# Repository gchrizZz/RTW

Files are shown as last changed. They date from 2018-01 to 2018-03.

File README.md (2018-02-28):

# RTW

Über dieses gitrepository können wir parallel am "Road to Wattens" - Projekt arbeiten.

Ordnerstruktur:
- 01_Projektmanagement:  Bereich für Bericht und Organisation
- 02_Quellcode:          Bereich für die Programmierung des Quadrocopters
- 03_Konstruktion:       Bereich für die CAD-Teile des Quadrocopters 
- 04_Elektrik:     Bereich für Platinenlayouts und Circuits
- 99_Archiv:             Bereich für Ablage und nicht mehr relevante Artefakte

CAD Modell von Mohne:
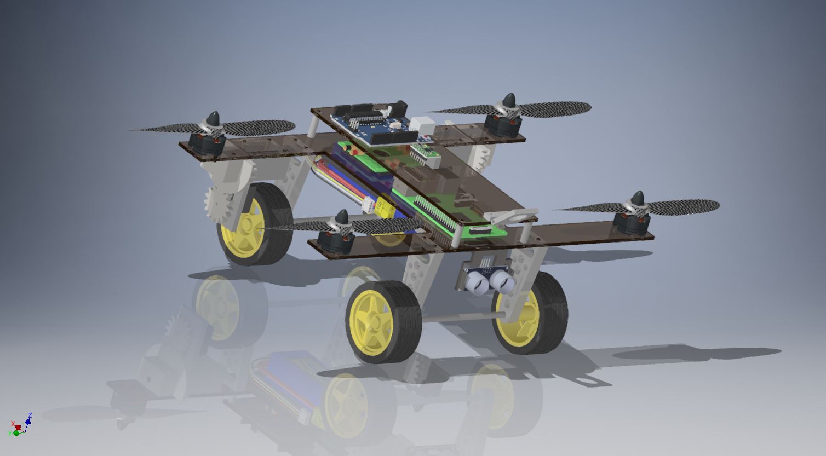
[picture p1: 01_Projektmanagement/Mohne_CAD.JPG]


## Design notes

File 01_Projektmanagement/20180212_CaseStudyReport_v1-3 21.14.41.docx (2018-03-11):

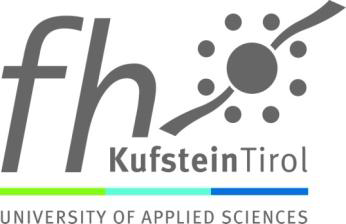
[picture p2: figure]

Mohne – Mobile Drohne

Abschlussbericht

Entwicklung eines autonomen Fahrzeuges für extraterrestrische Erkundungsmissionen

Eingereicht bei:

Fachhochschule Kufstein Tirol Bildungs GmbH

Studiengang Smart Products & Solutions

Verfasser:

Markus Wiesmüller

1710809534

Abgabedatum:

11.03.2018

# List of Figures

# List of Tables

# List of Abbreviation

IoT | Internet of Things
GM | Geschäftsmodell
GMI | Geschäftsmodell-Innovation
DBT | Digital Business Transformation
IT | Informationstechnik
EY | Ernst & Young
ROI | Return on Investment
KPI | Key Performance Indicator
MIT | Massachusetts Institute of Technologie
IKT | Informations- und Kommunikationstechnik
HR | Human Resources
BDI | Bundesverband der Deutschen Industrie e.V.
CEO | Chief Executive Officer
F&E | Forschung und Entwicklung

# Kurzfassung

In diesem Jahrhundert werden Menschen zum ersten Mal ihre Füße auf den Planeten Mars setzen – zumindest sehen dies durchaus realistische Pläne diverser Raumfahrtorganisationen. Bis es jedoch soweit ist, müssen weitere Projekte wie Phoenix oder InSight durchgeführt werden, um weitere Informationen über die Entstehung des Mars zu sammeln. Die Aufgabe, welche daher für das Projekt gestellt wurde, war die Entwicklung eines autonom agierenden Fahrzeugs, welches den widrigen Bedingungen auf dem Mars standhalten würde. Nach reichlicher Überlegung kamen wir zu dem Entschluss, dass eine Hybriddrohne, welche sowohl fahren als auch fliegen kann am besten für die Erkundungsmission geeignet sei, da dadurch die Möglichkeit gegeben ist, große Höhenunterschiede wie Berge oder Schluchten mühelos zu bewältigen und einen erheblichen Vorteil gegenüber konventionellen Mars-Rovern darstellt. Um diese Annahme zu bestätigen, hat das Team unterschiedliche Designvariationen in Betracht gezogen, bevor wir uns entschlossen haben einen Hybrid-Quadrocopter zu bauen. Die Nutzlast unserer Drohne umfasst eine Kamera und einen Ultraschallsensor, wodurch der Drohne ermöglicht wird sich autonom fortzubewegen. Hinsichtlich Projektmanagementmethodik entschieden wir uns für einen traditionellen Ansatz für die Gesamtplanung und für eine agile Methodik für die Einzelaufgaben.

Um die benötigten Komponenten für die Drohne zu produzieren wurden vom Fablab in Wattens die entsprechenden Maschinen und Geräte sowie hilfreiche Unterstützung zur Verfügung gestellt.

Um festzustellen, ob der Mars-Rover für einen Einsatz auf dem Mars geeignet ist, mussten fünf verschiedene Tracks absolviert werden. Es stellte sich jedoch schnell heraus, dass ein stabiler Flug und somit ein überwinden von Hindernissen aufgrund der fehlenden PID-Regelung nicht möglich war.

Letztendlich war dieses Konzept in der vorgegebenen Zeit für uns nicht realisierbar, weshalb man sich besser für ein anderes Design entschieden hätte. Man sollte sich daher nicht für ein Konzept entscheiden, von welchem man überzeugt ist, welches mit den gegebenen Ressourcen jedoch nicht umsetzbar ist. Dennoch zeigte unsere Drohne, dass sie bei weiterer Entwicklung das Potential für einen Einsatz auf dem Mars hat.

# Abstract

In this century, humans will set their feet on the planet Mars for the first time - at least this is what realistic plans of various space organisations see. Until then, however, further projects such as Phoenix or In-Sight will have to be carried out in order to gather further information on the origin of Mars. The task, therefore, was to develop an autonomous vehicle that would withstand the adverse conditions on Mars. After a lot of discussions, we came to the conclusion that a hybrid drone, which can drive as well as fly, is best suited for exploration missions, as it offers the possibility to effortlessly cope with big differences in altitude like mountains or canyons and represents a considerable advantage compared to conventional Mars rovers. To confirm this assumption, the team considered different design variations before we decided to build a hybrid quadrocopter. The payload of our drone includes a camera and an ultrasonic sensor, which enables the drone to move autonomously. With regard to project management methodology, we opted for a traditional approach to overall planning and an agile methodology for the individual tasks.

In order to produce the required components for the drone, the Fablab in Wattens provided the appropriate machines and equipment as well as helpful support.

In order to determine whether the Mars rover is suitable for a mission on Mars, five different tracks had to be completed. However, it soon became clear that a stable flight and thus the overcoming of obstacles was not possible due to the lack of PID regulation.

Ultimately, this concept was not feasible for us in the given time, which is why it would have been better to opt for a different design. Therefore, you should not decide on a concept that you are convinced of, but which cannot be implemented with the given resources. Nevertheless, our drone showed that it has the potential to be used on Mars during further development.

# 1. System Beschreibung

## 1.1 Mechanisches Konzept

Die Mohne ist ein sogenannter „Hybrid-Quadrocopter“, der sowohl zum Fahren als auch zum Fliegen konzipiert ist. Durch diese Hybrid-Nutzung ergeben sich große Vorteile. Auf dem Boden spart der Roboter Energie (im Verhältnis zur Fortbewegung in der Luft), während er in der Luft auch meterhohe Hindernisse überwinden kann. Nachfolgend wird das mechanische Konzept beider Varianten näher erläutert sowie in Abbildung 5 veranschaulicht.

### 1.1.1 Flugmodus

Die Mohne gehört zur Gruppe der Quadrocopter, bestehend aus vier Motoren die in H-Konfiguration angeordnet sind. Bei der H-Konfiguration sind die vier Motoren in 45° zur Flugrichtung versetzt, wobei der Abstand vom Kreuzmittelpunkt zu den einzelnen Motoren immer gleich groß ist.

Vier Propeller sind fest an den Motoren montiert und erzeugen den Auftrieb der Drohne, welcher sich über die Drehzahl der einzelnen Motoren verändern lässt. Übersteigt die durch die sich drehenden Propeller erzeugte Auftriebskraft die Anziehungskraft der Erde bzw. des Mars, so beginnt die Drohne zu schweben. Eine Erhöhung bzw. Verringerung der Drehzahl hat ein Steigen bzw. ein Sinken der Drohne zufolge.

Dadurch ergibt sich ein relativ einfacher mechanischer Aufbau, in dem es außer den Rotoren der Motoren keine weiteren beweglichen Teile für den Flugmodus gibt.

Überkreuz liegende Rotoren drehen dabei in die gleiche Richtung (Abbildung 1) und heben somit das um die Mitte der Drohne übertragene Drehmomente auf.

Bei exakt gleicher Drehgeschwindigkeit aller Propeller und keinen äußeren Störeinflüssen, steht die Drohne also exakt lotrecht über dem Boden. Dies eliminiert die Notwendigkeit einer Gierstabilisierung.

Um ein nach vorne fliegen zu ermöglichen, drehen sich die vorderen Rotoren langsamer als die hinteren, was ein nach vorne abkippen der Drohne zur Folge hat (Abbildung 2). Entsprechend wird ein nach hinten fliegen ermöglicht, indem die hinteren Rotoren langsamer als die vorderen drehen (Abbildung 3).

Abbildung 1: Quadrocopter: Motordrehrichtung

Abbildung 2: Quadrocopter: Vorwärtsbewegung

Abbildung 3: Quadrocopter: Rückwärtsbewegung

### 1.1.2 Fahrmodus

Um mit der Mohne auch fahren zu können, wurde eine Radaufhängung mit Achsen an die Drohne montiert. Allerdings werden dabei die Räder nicht von einem Motor betrieben, stattdessen wird die Schubleistung von den Propellern der Mohne erzeugt. Die hinteren Tragflächen des Quadrocopters lassen sich im Fahrmodus über Zahnräder um nahezu 90° nach vorne und hinten verstellen (Abbildung 4). In diesem Modus drehen sich nur die hinteren Propeller, wodurch ein Vorschub ähnlich wie bei einem Flugzeug bzw. Schiff erzeugt wird. Ein Abbremsen erfolgt indem die Propeller auf Umkehrschub gestellt werden. Sie erzeugen so einen nach vorne gerichteten Schub. Die Verstellung erfolgt dabei elektrisch.

+90°

-90°

Abbildung 4: Tragfläche mit Propeller: Verstellbar um +90° und -90°

### 1.1.3 Funktionsprinzip der Propeller

Wichtig für das Verständnis des Funktionsprinzips der Drohne ist, dass man sich grob phänomenologisch die Wirkungsweise von Propellern veranschaulicht, weil sich schon aus recht simplen Überlegungen Hinweise darauf ergeben, wie die Propeller sinnvollerweise ausgelegt werden müssen. Die Wirkungsweise eines Propellers, dessen Aufgabe sowohl im Flug- als auch im Fahrmodus darin besteht eine Drehleistung von 2πQn optimal in eine Schubleistung T_(v_A) umzusetzen, kann aus zwei Anschauungen gewonnen werden, die dann in jeweils unterschiedlichen Berechnungsmodellen münden:

- Impulsbetrachtung: Um einen Schub T nach vorne bzw. nach oben zu erzeugen, muss der Propeller die Luft nach hinten bzw. nach unten beschleunigen. Die Änderung des Impulses entspricht dabei dem Propellerschub. Die Theorie, die auf diesem Modell aufbaut, ist die Strahltheorie.
- Tragflügelbetrachtung: Die Wirkungsweise eines Propellers entspricht der eines Tragflügels. Der Auftrieb entspricht dabei dem Schub, der Widerstand dem Moment. Das Tragflügelmodell erklärt die Propellerwirkung an den einzelnen Flügelschnitten und ist als Traglinentheorie (nur radiale Diskretisierung) oder Tragflächentheorie bekannt.

Aus diesen beiden Wirkungsweisen lassen sich schon einige grundlegende Dinge qualitativ ableiten, ohne dass genaue mathematische Begründungen nötig sind.

Abbildung 5: Quadrocopter: Mechanisches Konzept

Motor

+

Propeller

Motor

+

Propeller

Motor

+

Propeller

Motor

+

Propeller

Rad

Rad

Rad

Rad

Servo

Servo

## 1.2 Sensing Concept

Um die Mohne autonom fliegen bzw. fahren zu lassen und Hindernisse und Ziele zu erkennen, wurde eine Kamera und ein Ultraschallsensor verbaut. Nachfolgend werden beide Sensoren näher beschrieben und das System im Gesamtkontext betrachtet.

### 1.2.1 Picamera

Mit der Kamera sollen vorher definierte Formen und Farben erkannt werden. Die Rückgabewerte an den Raspberry Pi sollen in der Logik die vorgesehene Funktion auslösen. Beispiele hierfür sind markierte Hindernisse und das Ziel. Anbei ein Auszug an angelernten Formen und Farben (Abbildung 6), hier ist auch das vorgegebene rote Quadrat enthalten. Die exakte Größe spielte keine Rolle, da wir in der Logik Ecken und Kanten zählen haben lassen und Farben erkennen.

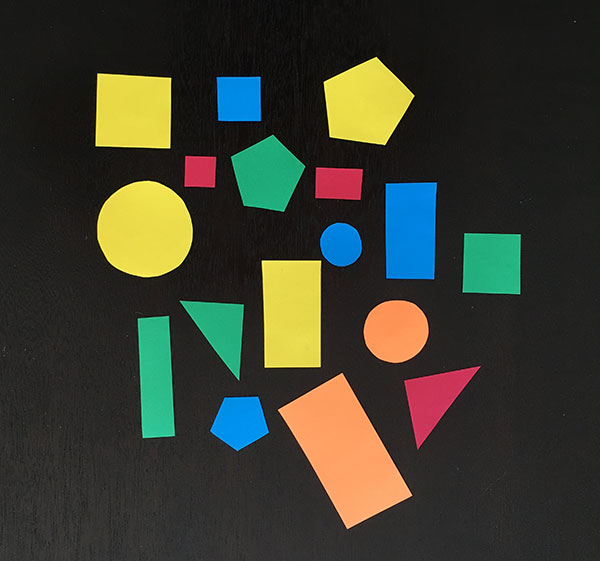
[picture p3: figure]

Abbildung 6: Angelernte Formen und Farben

### 1.2.2 Ultraschallabstandssensor

Mit dem Ultraschallabstandssensor (Abbildung 7) kann man mittels eines Ultraschalllautsprechers und eines Mikrofons den Abstand berührungslos zu einem Objekt messen. Das Prinzip (Abbildung 8) basiert darauf, dass die Schallgeschwindigkeit in der Luft bei gleichbleibender Temperatur nahezu konstant bleibt - bei 20°C beträgt sie 343,2m/s. Aus diesem Fakt kann man die Abstandsmessung in eine Zeitmessung überführen, welche dann von Mikro-Controllern einfach übernommen werden kann.

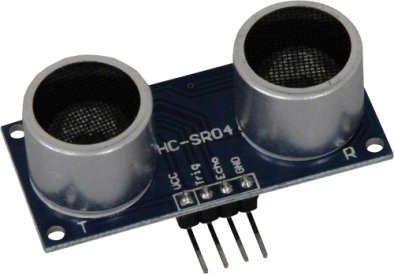
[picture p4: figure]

Abbildung 7: Ultraschallabstandssensor

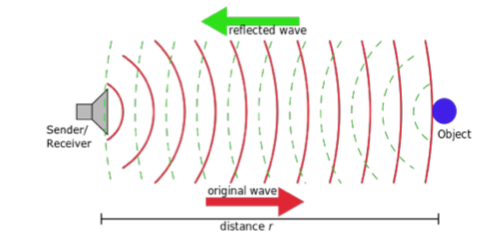
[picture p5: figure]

Abbildung 8: Funktionsprinzip Ultraschallabstandssensor

### 1.2.3 Gesamtsystem

Die unter Punkt 1.2.1 und 1.2.2 beschriebenen Sensoren unterstützen den Hybrid-Quadrocopter sich in seiner Umgebung zurechtzufinden und sich autonom fortzubewegen, Ziele zu erkennen und Hindernisse gekonnt zu überfliegen. Die Picamera dient dazu ein Ziel zu erkennen und dieses anzusteuern, mit Hilfe des Ultraschallsensors kann ein Hindernis erkannt werden, woraufhin in den Flugmodus gewechselt wird, um das Hindernis zu überfliegen und um nach einer bestimmten Zeit x zu landen und wieder in den Fahrmodus zu wechseln. Wie in Abbildung 9 veranschaulicht sind dabei beide Sensoren mit einem Micro-Controller verbunden.

Abbildung 9: Quadrocopter: Sensorkonzept

Controller

Kamera

Ultraschallsensor

# 2. Materialien und Methoden

Um das Projekt zu realisieren und die Mohne zu entwickeln, wurde Seitens des Auftraggebers verschiedene Materialien und Werkzeugmaschinen sowie ein Budget von 40€ zur Verfügung gestellt.

Es gab viele Faktoren, die dazu beitrugen, wie dieser Hybrid-Quadrocopter konstruiert werden sollte. Das Team musste zuerst berücksichtigen, dass die Drohne Testflüge absolvieren musste, von denen sie gegebenenfalls nicht in einem Stück zurückkehrt. Hinzu kam, dass das Gewicht der für die Herstellung der Drohne verwendeten Materialien sorgfältig geprüft werden musste, damit das Gewichtslimit und auch die Größe für den Wettbewerb nicht überschritten wurde. Schließlich musste das Design auf eine Art und Weise erstellt werden, welches leicht mit den zur Verfügung stehenden Materialien und Werkzeugmaschinen umgesetzt werden konnte. Zudem musste das Design die Elektronik vor Wasser schützen. Aufgrund des entscheidensten Faktors, die für die Produktion zur Verfügung stehenden Zeit, wurde entschieden, Lasercutten, 3D-Druck, Schneiden, Schleifen, Fräsen und verbinden mit Schrauben zu verwenden. Dieser Prozess wurde als am schnellsten und am leichtesten reproduzierbar bestimmt, falls erforderlich. Der erste Schritt in diesem Prozess war das Design der Drohne zu entwerfen. Dafür wurde die in Abschnitt 2.3.1 beschriebene CAD-Software Autodesk Inventor verwendet. Im nächsten Schritt wurde bestimmt, wie die einzelnen Komponenten hergestellt und welche Materialen dafür verwendet werden sollten. Komponenten wir Arduino, Raspberry Pi und Sensoren wurden zur Verfügung gestellt. Da jedoch kein Breadboard verwendet werden durfte, wurde mit Hilfe der in 2.3.2 beschriebenen Software ein Leiterplatten-Layout erstellt, welches mit Hilfe einer Fräsmaschine gefertigt wurde.

In diesem Kapitel werden die bereitgestellten Materialien aufgelistet, die verfügbaren Maschinen vorgestellt sowie eine Vorstellung der verwendeten Software.

## 2.1 Materialien

Aus der Tabelle 1 sind die Materialien und Maße der vom Kunden zur Verfügung gestellten Werkstoffe ersichtlich.

Tabelle 1: Zur Verfügung gestelltes Material

Material | Maße in mm (l x b x h)
Holz | 800 x 600 x 3,8
Plexiglas | 600 x 400 x 3

## 2.2 Manufacturing Technologies

Um das Projekt zu realisieren kamen unterschiedliche Werkzeugmaschinen zum einsatz, welche aus Tabelle 2 ersichtlich sind. Auf eine nähere Beschreibung der Handhabung der Maschinen wird in diesem Bericht bewusst verzichtet.

Tabelle 2: Werkzeug und Maschinen

Werkzeug / Maschine
Bohr-Fräsmaschine Optimum BF 16 Vario

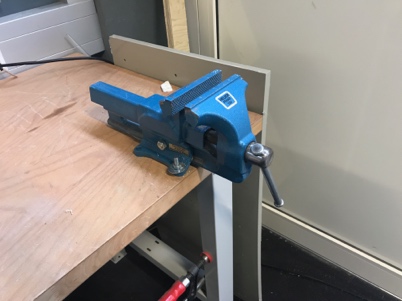
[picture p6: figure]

Schraubstock
Schleifmaschine Holzstar BTS 150

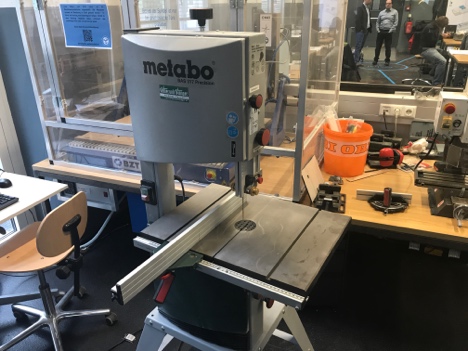
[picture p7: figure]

Bandsäge Metabo BAS 317 Precision
Digitaler Messschieber Scala 150mm

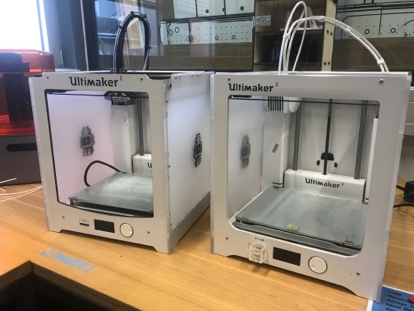
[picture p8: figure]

Ultimaker 2 3D-Drucker
Ultimaker 3 Dual Extruder 3D-Drucker
Fräsmaschine Roland SRM-20

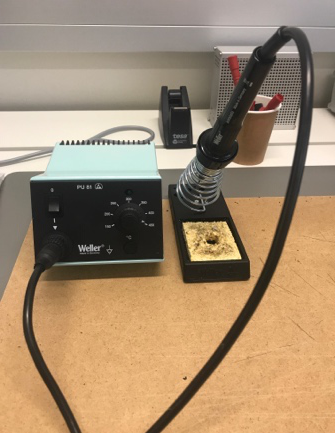
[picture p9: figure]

Lötstation Weller WS 81
Lasergravierer Trotec Speedy 360

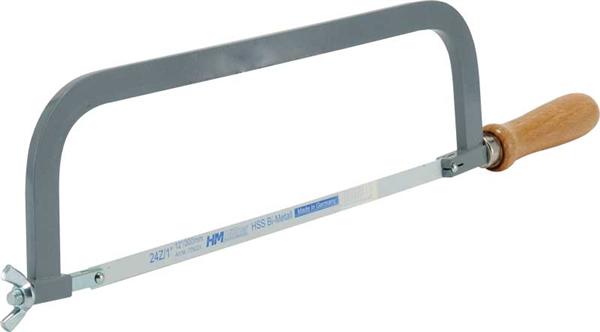
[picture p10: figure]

Metallsäge
Schraubenzieher

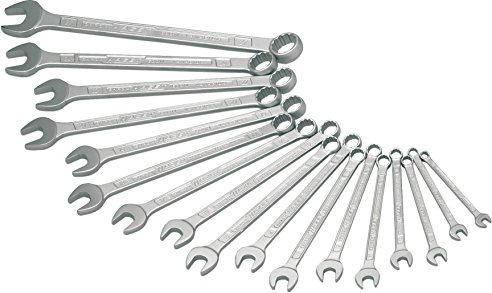
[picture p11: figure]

Schraubenschlüssel

## 2.3 Software Tools

Um das Projekt zu realisieren, wurden die nachfolgenden Softwareprogramme verwendet. Zum einen wurde Autodesk Inventor Professional verwendet, um ein 3D CAD-Modell der Mohne zu erstellen (Abbildung 10). Die einzelnen Komponenten sind in Tabelle 3 aufgelistet. Zum anderen wurde für die Konstruktion der Leiterplatte das Programm EAGLE der Firma Autodesk verwendet. Weitere Software Tools wurden für die Programmierung benötigt.

### 2.3.1 Autodesk Inventor Professional

Autodesk Inventor ist eine von Autodesk entwickelte 3D-CAD-Software für die Volumenmodellierung, mit der digitale 3D-Prototypen erstellt werden können. Es wird für 3D-Konstruktion, Design-Kommunikation, Werkzeugherstellung und Produktsimulation verwendet. Diese Software ermöglicht es Benutzern, genaue 3D-Modelle zu erstellen, um Produkte zu entwerfen, zu visualisieren und zu simulieren, bevor sie gebaut werden.


Die Software ermöglicht zudem 2D- und 3D-Daten in eine einzige Designumgebung zu integrieren und so eine virtuelle Darstellung des Endprodukts zu erstellen, mit der die Form, Passform und Funktion des Produkts vor dem Bau validieren werden kann. Autodesk Inventor enthält leistungsstarke parametrische, direkte Bearbeitungs- und Freiform-Modellierungswerkzeuge sowie Multi-CAD-Übersetzungsfunktionen und DWG Zeichnungen nach Industriestandard, wodurch Entwicklungskosten gesenkt, schnellere Time-to-Market realisiert und großartige Produkte entwickelt werden können.

Abbildung 10: CAD-Modell des Hybrid-Quadrocopters

Tabelle 3: Komponentenübersicht

Name | Anzahl
Chassis mit motorlöcher | 1
Platzhalter Zylinder Klein | 4
Metall Stab M5 | 1
Chassis-2 | 1
Kegelrad | 1
EMax Motor | 4
RaspberryPi2 STEP214 | 1
Metall Stab M5_MIR | 1
StirnradUNDServo_MIR | 1
Propeller | 4
arduino uno | 1
MPU 6050 IMU | 1
Abstandhalter_MPU | 1
LiPo Akku | 1
PDB | 4
Ultrasonic Sensor Halterung | 1
USS | 1
Wheel ALL | 2
Radaufhängung | 4
Wheel ALL1_MIR | 2
Achse | 2
Kamerahalterung | 1
ESC | 4
M3 Schrauben | 27
M3 Beilagscheiben | 27
M3 Muttern | 27
Raspberry Pi Camera | 1
Stirnzahnrad1 | 2
Stirnzahnrad2 | 2
servo_SM-S2309S | 2

### 2.3.2 Autodesk EAGLE

EAGLE ist eine skriptfähige EDA-Anwendung (Electronic Design Automation) mit Schaltplan-Erfassung, Leiterplatten-Layout, Auto-Router und CAM-Funktionen (Computer Aided Manufacturing). EAGLE steht dabei für Easy Applicable Grafischer Layout-Editor.

Das Programm bietet eine grafische Benutzeroberfläche und ein Menüsystem mit mehreren Fenstern für die Bearbeitung, das Projektmanagement und die Anpassung der Schnittstellen- und Designparameter. Das System kann über Maus, Tastaturkürzel oder durch Eingabe bestimmter Befehle in einer eingebetteten Befehlszeile gesteuert werden. Mehrere Wiederholungsbefehle können zu Skriptdateien kombiniert werden. Es ist auch möglich, Entwurfsdateien unter Verwendung einer EAGLE-spezifischen objektorientierten Programmiersprache zu untersuchen.

### 2.3.3 Arduino IDE

Arduino bringt eine eigene integrierte Entwicklungsumgebung (IDE) mit, die auf Wiring IDE basiert. Dabei handelt es sich um eine Java-Anwendung, die für die gängigen Plattformen Windows, Linux und MacOS kostenlos verfügbar ist. Sie basiert auf der IDE von Processing, einer auf die Einsatzbereiche Grafik, Simulation und Animation spezialisierten Entwicklungsumgebung. Die Arduino-IDE bringt einen Code-Editor mit und bindet gcc als Compiler ein. Zusätzlich werden die avr-gcc-Library und weitere Arduino-Librarys eingebunden, die die Programmierung in C und C++ stark vereinfachen. Arduino kann verwendet werden, um eigenständige interaktive Objekte zu steuern oder um Softwareanwendungen auf Computern zu interagieren (z.B. Adobe Flash, Processing, Max/MSP, Pure Data, diverse Skriptsprachen, etc.)

Für ein funktionstüchtiges Programm genügt es, zwei Funktionen zu definieren:

- setup() – wird beim Start des Programms (entweder nach dem Übertragen auf das Board oder nach Drücken des Reset-Tasters) einmalig aufgerufen, um z. B. Pins als Eingang oder Ausgang zu definieren.
- loop() – wird durchgehend immer wieder durchlaufen, solange das Arduino-Board eingeschaltet ist.

### 2.3.4 Raspbian

Raspbian ist ein kostenloses Betriebssystem, das auf Debian basiert und für die Raspberry Pi-Hardware optimiert ist. Ein Betriebssystem ist die Menge der grundlegenden Programme und Dienstprogramme, die den Raspberry Pi laufen lassen. Raspbian bietet jedoch mehr als ein reines Betriebssystem: Es enthält mehr als 35.000 Pakete, vorkompilierte Software in einem schönen Format für die einfache Installation auf dem Raspberry Pi. Dieses Betriebssystem basiert auf einem Debian-9-System (Debian Stretch) der ARM-hard-float-Architektur (armhf) mit Anpassungen an den Befehlssatz für den ARMv6-Prozessor. Als grafische Oberfläche wird LXDE vorkonfiguriert. Das etwa 3 GB große Image kann auf SD-Karten mit 4 GB oder mehr übertragen werden. Nach dem Bootvorgang kann die Größe der Raspbian-Partition auf die gesamte SD-Karte erweitert werden. Die Raspberry Pi Foundation erstellt auf Basis der Raspbian-Distribution ein eigenes Raspbian-Image mit passender Firmware für die Raspberry-Pi-Modelle, es wird daher empfohlen, die Distribution immer von der Raspberry Pi Foundation zu beziehen.

### 2.3.5 Python

Das Pi im Namen des Raspberry Pi leitet sich von der Programmiersprache Python ab: Die Schöpfer des Minicomputers wollten damit zum Ausdruck bringen, dass diese moderne Skriptsprache besonders zu empfehlen ist.

Python ist eine universelle, üblicherweise interpretierte höhere Programmiersprache. Sie hat den Anspruch, einen gut lesbaren, knappen Programmierstil zu fördern. So werden beispielsweise Blöcke nicht durch geschweifte Klammern, sondern durch Einrückungen strukturiert.

Python unterstützt mehrere Programmierparadigmen, z. B. die objektorientierte, die aspektorientierte und die funktionale Programmierung. Ferner bietet es eine dynamische Typisierung. Wie viele dynamische Sprachen wird Python oft als Skriptsprache genutzt.

Die Sprache hat ein offenes, gemeinschaftsbasiertes Entwicklungsmodell, das durch die gemeinnützige Python Software Foundation, die de facto die Definition der Sprache in der Referenzumsetzung CPython pflegt, gestützt wird.

Wegen ihrer klaren und übersichtlichen Syntax gilt Python als einfach zu erlernen. Sie besitzt eine umfangreiche Standardbibliothek und zahlreiche Pakete im Python Package Index.

Zur Standardinstallation von Python gehört eine integrierte Entwicklungsumge- bung namens IDLE.

Raspbian bringt die Python-Entwicklungsumgebung IDLE bereits vorinstalliert auf dem Desktop mit, sodass bei Bedarf direkt losgelegt werden kann.

IDLE besteht im Wesentlichen aus drei Komponenten:

- Die Python-Shell: Beim Starten von IDEL öffnet sich zuerst das Python-Shell- Fenster. Die Shell ist eine Anwendung, mit der Sie direkt mit dem Python-In- terpreter kommunizieren können: Sie können auf der Kommandozeile einzel- ne Python-Anweisungen eingeben und ausführen lassen. Ein Python-Pro- gramm, das eine Bildschirmausgabe liefert, gibt diese in einem Shell-Fenster aus.
- Der Programmeditor: Das ist eine Art Textverarbeitungsprogramm zum Schreiben von Programmen. Sie starten den Programmeditor vom Shell-Fens- ter aus (FILE|NEW WINDOW).
- Der Debugger: Er dient dazu, den Lauf eines Programms zu kontrollieren, um logische Fehler zu finden.

### 2.3.6 Samba

Sabba ist ein freies Programmpaket, das es ermöglicht Windows-Funktionen wie die Datei- und Druckdienste unter anderen Betriebssystemen zu nutzen und die Rolle eines Domain Controllers anzunehmen. Es implementiert hierfür unter anderem das Server Message Block/Common Internet File System-Protokoll (SMB/CIFS-Protokoll).

Da die Software unter der General Public Licence (GPL) kostenfrei verfügbar ist, wird sie als Alternative zu Microsoft-Windows-Server-Betriebssystem eingesetzt.

# 4. System Life Cycle

Within the scope of the Mars Explorer project, the knowledge gained from the courses Systems Engineering, Embedded Systems and Project Management will be applied. In addition, a Fablab environment, mechanical and electronic component manufacturing and PCB production will be explored.

## 4.1 System Requirements

### 4.1.1 Mandatory Requirements

The aim of the project is to develop an autonomous vehicle suitable for extraterrestrial exploration missions with the provided components, materials, machinery and budget. The suitability is tested on five test tracks. The requirements for the vehicle are as following:

- Undamaged fall from a maximum drop height of 0.5 m
- Protection against dust and water
- Dimensions for rocket transport:
  - Lenght < 65 cm
  - Width < 48 cm
  - Height < 30 cm
- Weight oft he vehicle:
  - mRover < 10 kg (Earth)
  - mRover < 4,5 kg (Mars)
- Type of movement freely selectable, but autonomous
- Budget: 40 €

### 4.1.2 Preference Requirements

The project should lead to an autonomous hybrid quadrocopter, which can overcome the tracks described under 3.6 by changing between driving and flight mode and recognizing its environment by means of an ultrasonic sensor and camera and responding accordingly to different situations. The heart of the vehicle is a Raspberry Pi and an Arduino which receive, process and transmit data.

Sub-goals for the project are:

- Design and manufacture the chassis
- Design and manufacture the rotary mechanism to switch between ride and flight modes
- Design and manufacture printed circuit boards (PCB)
- Programming of the engine control incl. ESC calibration to create the conditions for flying
- Autonomous mode using sensors (programming for ultrasonic sensor and camera)
- Control code and PIC control to keep the Quadrocopter stable

### 4.1.3 Limitations

Switching on and off takes place in manual mode, while the Mohne is operated autonomous during flying and driving. The distance to the ground is not measured. Overcoming obstacles is achieved by changing from driving mode to flight mode and returning to driving mode after a pre-set time.

The system has to work only under good weather conditions and on given courses, therefore only a straight flight is realized.

## 4.2 Design Alternatives

In order to decide upon a design for this project, certain limiting factors had to be taken into account, namely the maximum size and maximum permissible weight that the vehicle may have in order to be still be able to be transported by the launch vehicle to Mars. Even under the condition that the electronic components, which would be incased and secured somewhere inside the fuselage, must be protected from dust and water, the possibilities were further restricted. The given budget and time limit, as well as the materials and machines available, limited further possibilities. After some thought and research was carried out to find the easiest way to overcome the individual hurdles of the test tracks, it was decided that a hybrid quadrocopter would be developed. Due to the fact that drones are becoming increasingly popular and are being used in an increasing number of applications, we wanted to meet this challenge and abandon the construction of a conventional Mars rover.

## 4.3 Model the System

Normally, models are developed for almost all alternative designs. The preferred alternative model is then expanded and used to manage the system throughout its entire system lifecycle. Due to the short development time, no models were developed for alternative designs. First and foremost, the following models are also intended to describe the system.

### 4.3.1 System and Subsystem

Hybrid-Quadcopter
Actuator
Avionics
Frame
Power Distribution
Motor
Propeller
Servo
Sensors
Battery
Wires
Power Distribution Board
Computer
Microcontroller
Carrier
Chassis
Rotary mechanism
ESCThe overall system was partitioned into four subsystems (Abbildung 11) which made it easier to design, understand and test the system and which made it easier to work in teams.

Abbildung 11: System and Subsystems

### 4.3.2 Make or Bye

In a make-or-buy decision, the most important factors to consider are part of quantitative analysis, such as the associated costs of production and whether the business has the capacity to produce at required levels. As a result, it was relatively easy to decide which parts to buy and which to produce. The production of the electronic components could not be realized by us, which is why they were purchased, but the mechanical components were designed and manufactured by us (Tabelle 4).

Tabelle 4: Make or Bye Decision

Motor | Commercially available subsystem
Propeller | Commercially available subsystem
ESC | Commercially available subsystem
Servo | Commercially available subsystem
Gyro and USS | Commercially available subsystem
Arduino | Commercially available subsystem
Raspberry Pi | Commercially available subsystem
Carrier | In-house-design
Chassis | In-house-design
Rotary mechanism | In-house-design
Battery | Commercially available subsystem
Wires | Commercially available subsystem
Power Distribution Board | First Make, after “burn out” Buy
Wiring | Commercially available subsystem
Sensors | Commercially available subsystem

### 4.3.3 System Architecture

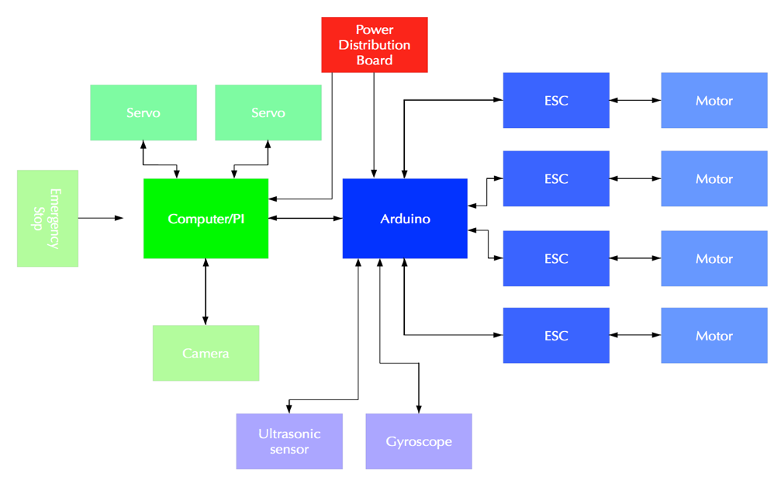
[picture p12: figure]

Abbildung 12: System architecture Mohne

### 4.3.4 Failure Mode and Effects Analysis (FMEA)

The procedure used to evaluate the various modes of failure in our drone design takes into consideration the severity, probability of occurrence and detectability for each failure mode as well as the root causes. Based on the values assigned to each category, the risk priority and criticality of each cause are calculated. Our failure analysis focused on four failure modes; mobility, navigation, structural and data acquisition (Tabelle 5). We determined the key failures modes to be mobility and navigation. In each of these two cases, control system and wiring failure are the root causes with the highest risk priorities and criticalities.

Tabelle 5: FMEA

Possible Effect | Root Cause | Potential Indicators | Potential Cause(s) of Failure | Severity | Probability of Occurence | Detectability | Risk Prirority | Criticality
Mobility | dead battery | will not power motor | Battery not charged | 5 | 3 | 1 | 15 | 15
| controls failure | Motors, servos and PID controller failure | Programming error | 5 | 9 | 9 | 405 | 45
| wiring harness connections | will not start or run correctly | Grounding corrosion | 8 | 8 | 9 | 576 | 64
Navigation | Wiring failure | Complete navigation failure | Wiring error | 8 | 7 | 2 | 112 | 56
| Controls Failure | Complete navigation failure | Programming error | 5 | 9 | 9 | 405 | 45
| Object sensing hardware failure | Part damage | Wiring control failure | 5 | 3 | 3 | 45 | 15
| Rotary mechanism failure | Steering failure | Impact on gear | 5 | 5 | 1 | 25 | 25
Structural | Frame cracking | No component support | Impact on frame | 10 | 3 | 4 | 120 | 30
| Engin mount | Engin falls out | Engin mount wear | 2 | 1 | 1 | 2 | 2
Data Acquisition | Camera not working | No video recording | Weather proofing controls/wire | 1 | 5 | 2 | 10 | 5
| Ultrasonic sensor not working | No distance measurement | Weather proofing controls/wire | 1 | 5 | 3 | 15 | 5
| Incorrect wiring | Will not move | Wiring error | 2 | 2 | 4 | 16 | 4
| Controls failure | No/incorrect data | Programming error | 1 | 2 | 5 | 10 | 2

## 4.4 Integrate System Components

For system integration, an important point is that each part is well developed for itself and somehow works alone. This makes it easier to repair things because it is easier to repair a small part than the whole system. The second important point of system integration is the combination of all subsystems into a fully functional system. Picture 13 fits perfectly to show the integration of subsystems into the overall system "Mohne". The parts of the puzzle that were not part of our project were crossed out and yet there are many parts that we had to combine. Two parts of the puzzle which caused difficulties due to time constraints. This will be explained later, but clearly shows the importance of well integrated system components.

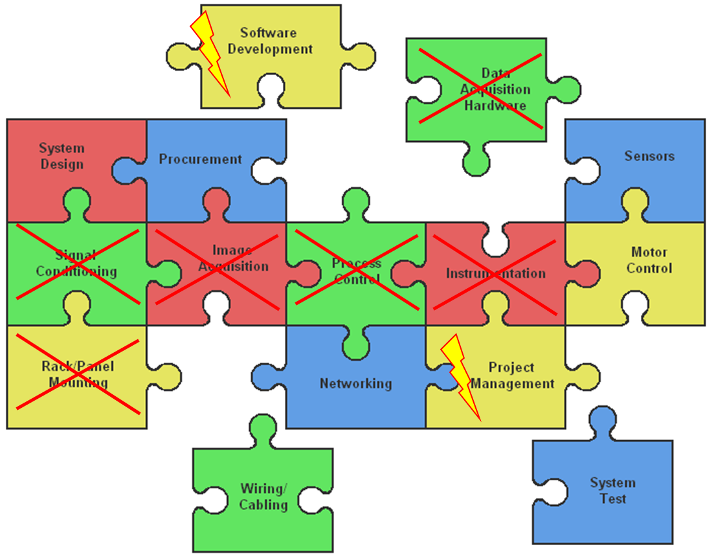
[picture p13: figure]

Abbildung 13: Integration of subsuystems into the overall system

## 4.5 Launch the System

### 4.5.1 Timeline

For the overall timeline (Abbildung 14) it was decided to use a traditional planning Method “waterfall”. Project phases were structured, discussed and described and milestones with goals to be reach after each phase were set up.

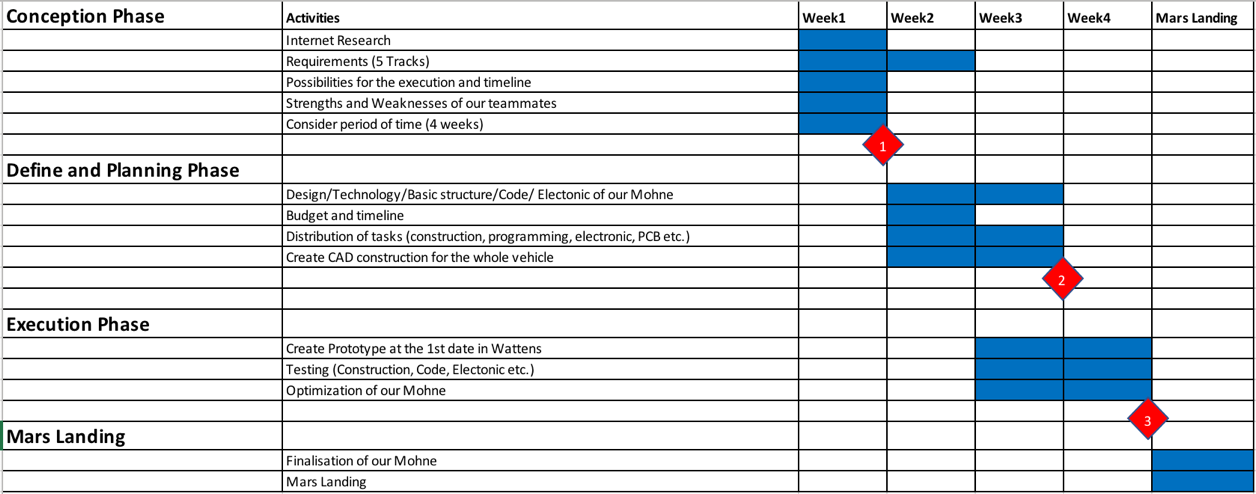
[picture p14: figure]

Abbildung 14:Project Timeline

Therefore, tasks (Tabelle 6) were set up in the agile planning tool on github. Traditional planning methods (overall planning) were combined with agile project methods (scrum mode doing the tasks).

Tabelle 6: Project Tasks and Responsibility

Task | Team Member(s)
Design decision | all
Design and manufacture chassis | Duregger, Jungwirth, Gruber
Image recognition | Paula, Gruber
Camera mounting | Duregger, Jungwirth
Suspension, axles and shaft | Duregger, Jungwirth, Gruber
PCB layout | Möbes
Electronics | Möbes, Gruber
Servo mount + rotary mechanism | Duregger, Jungwirth, Gruber
Engine mount | Duregger, Jungwirth, Gruber
Spacer between boards | Duregger, Jungwirth, Gruber
ESC calibration and motor control | Möbes, Gruber
Plug connection HV battery and power board | Möbes
Control code | Möbes, Paula, Gruber
Project management and documentation | Wiesmüller
Assembly | Wiesmüller, Gruber
Cost analysis | Gruber
Component selection and ordering | all
Flight and system test | all

### 4.5.2 Budget

Because of the very small budget of 40€ a little budget planning had to be done. Unfortunately, the project could not be realized with the available budget, which is why the budget was a bit overdrawn. For this small budget the project was much too ambitious.

Tabelle 7: Budget Calculation

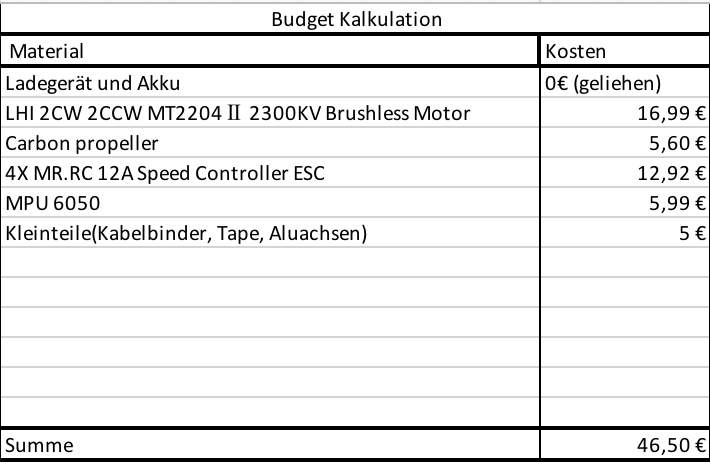
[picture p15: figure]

## 4.6 Assess Performance

During the entire development phase, the performance of the system was measured and tested again and again. These measurements were necessary to verify that the system met its requirements. First of all, it was tested at the beginning whether the rotary mechanism works as expected, which was the basis for the change between driving and flying mode.

Tests were also carried out again and again in order to ensure the image recognition and distance measurement to ensure autonomous navigation. Another important point that has been tested continuously is the engine control to ensure that the quadcopter can move.

In order to determine whether the project is suitable for a mission on Mars, whether it can move autonomously and fulfills the expectations and wishes of the client, 5 test tracks (Tabelle 8) had to be completed, which are described below. In addition, the clients inspected whether the required minimum requirements in terms of size, weight and stability were met.

Tabelle 8: Test Tracks

Track | Dimensions (l x w) | Surface | Environment condition | Goal
1 | 3m x 1m | Concrete | Indoor area | Drive straight on
2 | 3m x 1m | Concrete | Dust simulation by means of spray bottles | passing through without defects
3 | 3m x 1m | Wooden steps with different heights (10cm, 20cm, 30cm, 40cm, 50cm, 60cm) | Indoor area | Overcoming obstacles
4 | 3m x 1m | Rocks with different heights (10-60 cm) | Indoor area, rocks colored and marked with symbol | Cross the track, avoid obstacles
5 | unbekannt | Unknown (snow, ice, sand, etc.), rocks with different heights (10-60cm) | Outdoor area, rocks colored and marked with symbol | Survive

Image 15 shows the symbol the rocks are marked with

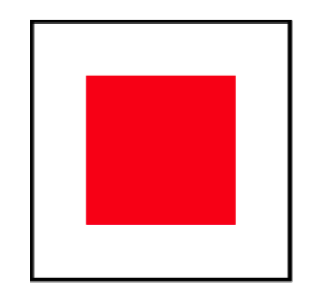
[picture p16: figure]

Abbildung 15: Obsticle-ID

## 4.7 Results, Conclusion and Recommendations

### 4.7.1 Results

This project lasted 4 weeks and involved a lot of research, testing and analysis. At the beginning of the project, the team created initial project specifications as detailed in section 3.1 which served as guidelines for the Mohne. A review was done to see which specifications the project fulfilled and which ones it did not.

- The drone met the maximum size and weight requirements
- The drop test from a height of 0.5m was passed unscathed
- The drone met the requirements for dust and water resistance
- The drone failed to meet the requirement to not exceed 40 € in cost. The total cost of the drone was 46,50 €
- The drone met the emergency stop requirement
- The drone met the requirement to detect its environment
- The change between flight and driving mode could be realized
- The drone was able to drive straight on
- The requirement to fly was only partially met. Although several flight tests were carried out, it could not be realized that all four propellers were supplied with consistent electricity distribution, consequently the drone flight was not stable enough. The problem was detected, but the PID control required for this could not be implemented due to time constraints.
- Because of the previous problem, the obstacles could not be overcome

### 4.7.2 Conclusion

The final results showed that not all specifications and goals set at the beginning of the project were met. Although the fully autonomous flight was not achieved, the team made a significant development towards creating a low-cost, lightweight unmanned hybrid vehicle capable of surveillance with its implementation of a camera system and an ultrasonic sensor. Several design iterations were completed to create a vehicle that would meet the project goals and the final prototype demonstrated potential for success with the project goals. As described earlier in section 3.6, several tests were performed to ensure the designed prototype would fly and ride successfully. If more time was available, the team would have been able to design a more robust control system that would ensure stable flight. Overall, an unmanned aircraft vehicle was fully realized in this project. The hybrid quadcopter demonstrated it was able to drive and fly, but it lacked stability. Further iterations of this project would ensure its future success.

### 4.7.3 Recommendations

Several lessons were learned during the course of this project and thus the team has several recommendations. From a controls aspect, more sensors would be helpful for more precision or capabilities. Another ultrasonic sensor could be used to determine the altitude. The implementation of additional camera modules could create a 360-degree perception to avoid obstacles. In the next step it could also be realized to drive and fly curves. The execution of simulations and calculations would lead to a more effective design.

# 5. Diagrams

Nachfolgend werden Use Case Diagram, Structural Model, Interaction Model und Behavior Model für ein besseres Verständnis des Softwaresystems, welche Komponente eine andere beeinflusst und in welcher Form dies geschieht, wie die Kommunikation zwischen Raspberry Pi und Arduino gestaltet ist sowie das Verhalten eines Systems, entwickelt und beschrieben.

## 5.1 Use Case Diagram

Das gezeigte Use Case Diagram (Abbildung 16) zeigt die Interaktionen zwischen externen Akteuren (User, PiCam, USS, GYRO, Controller) und dem betrachteten System (Autonome Fortbewegung). Während der User nur für das Starten und den Not-Aus der Mohne zuständig ist, sind die anderen Akteure, sowie die Steuerung der Motoren und Servos, für die Steuerung der Drohne zuständig. Darüber hinaus sind PiCam, Ultraschallsensor und Gyro für die Umgebungserkennung zuständig und Leiten die gemessenen Werte an den Controller weiter.

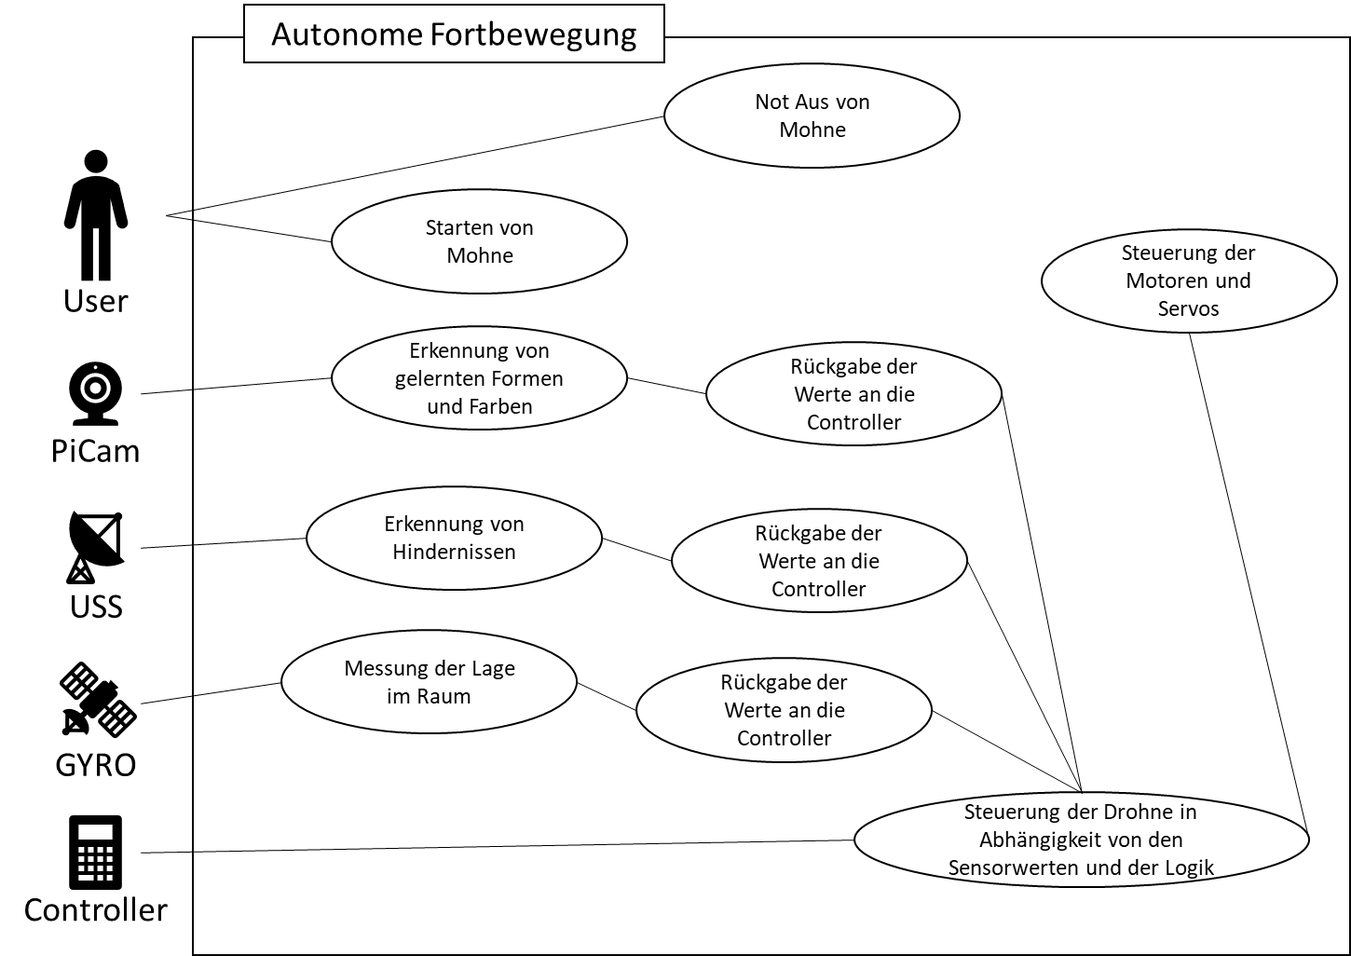
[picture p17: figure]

Abbildung 16: Use Case Diagram

## 5.2 Structural Model

Die Mohne ist ein Fluggerät, welches durch das Zusammenspiel von verschiedenen Faktoren und Systemkomponenten bestimmt wird. Die Abhängigkeit der einzelnen Systemteile wird in der nachstehenden Graphik (Abbildung 17) dargestellt. Durch die dauerhafte Kommunikation untereinander, kann eine Überwachung und Kontrolle der einzelnen Komponenten sichergestellt werden. Dabei stehen die einzelnen Systemteile in einer direkten Abhängigkeit. Im Zentrum der Struktur stehen hier der Arduino Uno bzw. der Raspberry Pi 3. Diese verarbeiten die eingehenden Daten des Gyroskops, des MPU´s, des Ultraschallsensors und der Kamera. Durch die Datenerfassung des der genannten Eingangssysteme werden die Motoren bzw. die Motorleistung entsprechend gesteuert und angepasst. Die erfassten Daten werden vom Gyroskope und MPU an Arduino/Raspberry Pi weitergegeben und diese steuern bzw. überwachend die Motorleistung und passen diese entsprechend an, damit die „Mohne“ kontrolliert fliegen kann. Ebenfalls werden die Servoelemente der „Mohne“ durch den Arduino und Rasberry Pi gesteuert und kontrolliert, welche benötigt werden um sich am Boden vorwärts bewegen zu können.

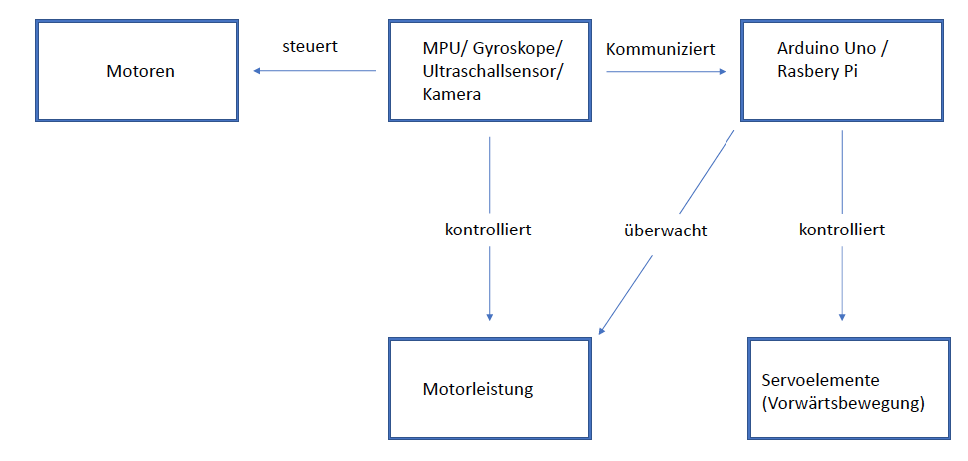
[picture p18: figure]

Abbildung 17: Structural Model

## 5.3 Interaction Model

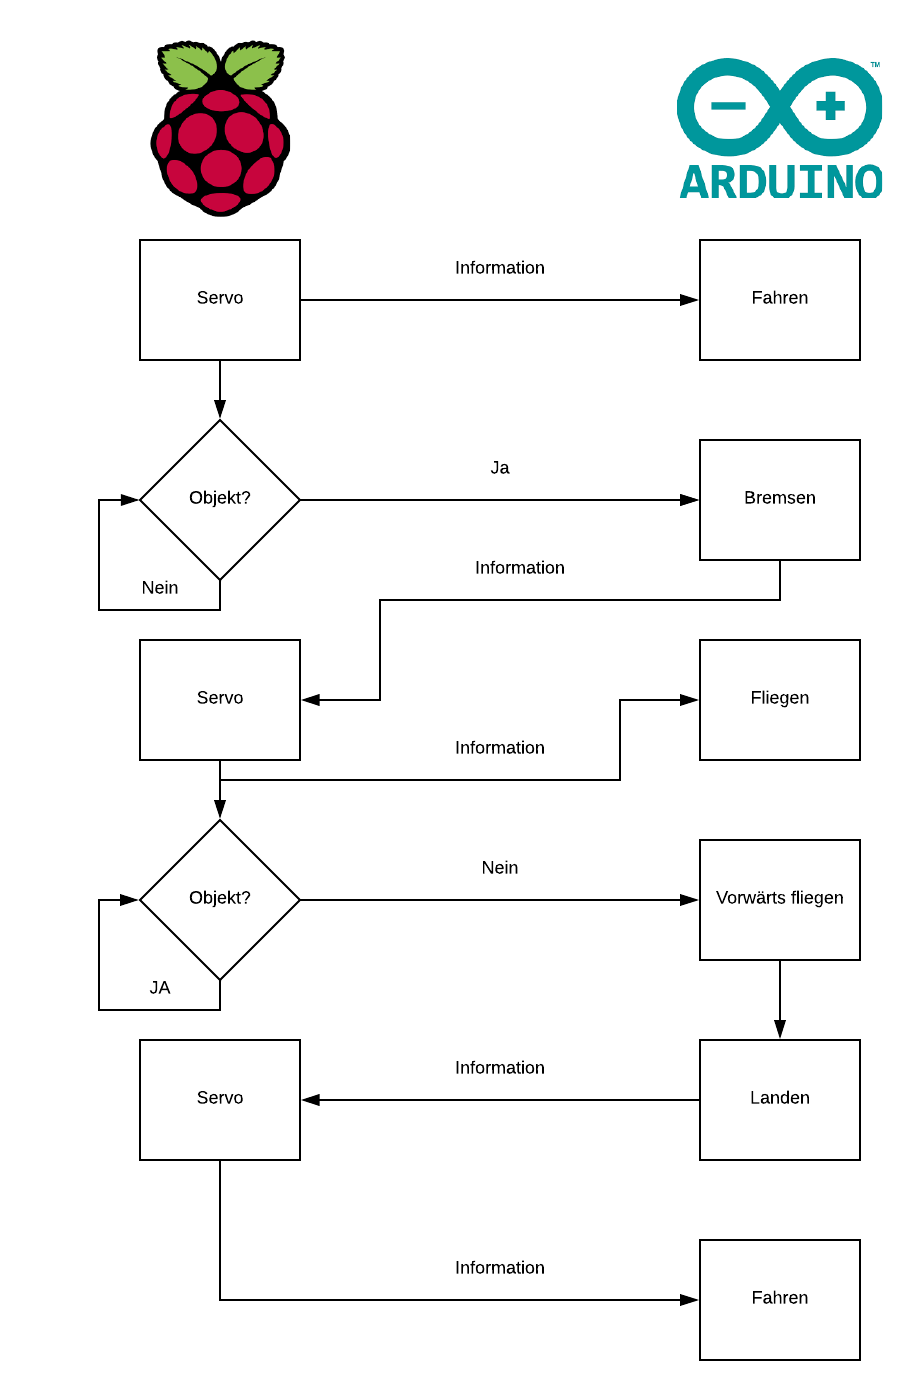
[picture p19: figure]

Abbildung 18: Interaction Model

## 5.4 Behavior Model

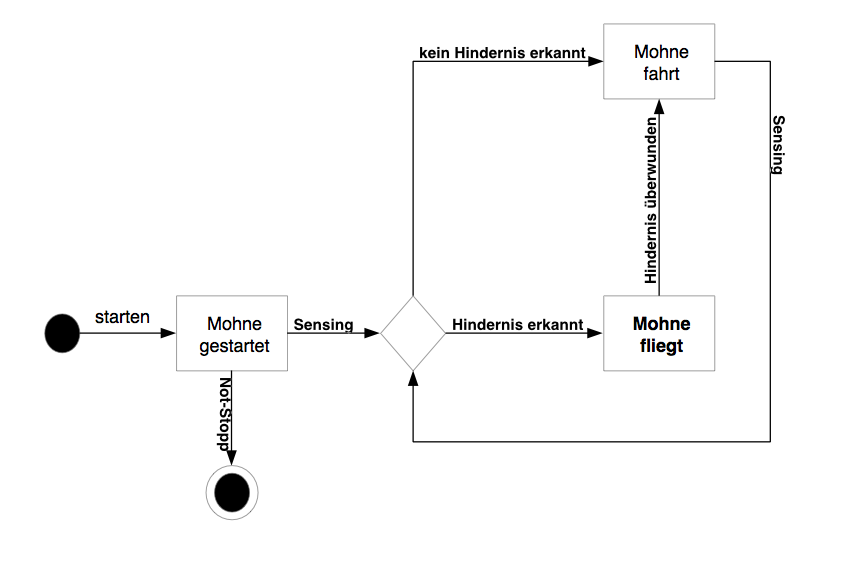
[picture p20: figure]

# 6. Version Control

Abbildung 19: Behavior Model

https://github.com/gchrizZz/RTW

# 7. Design of PCB

## 7.1 Breadboard

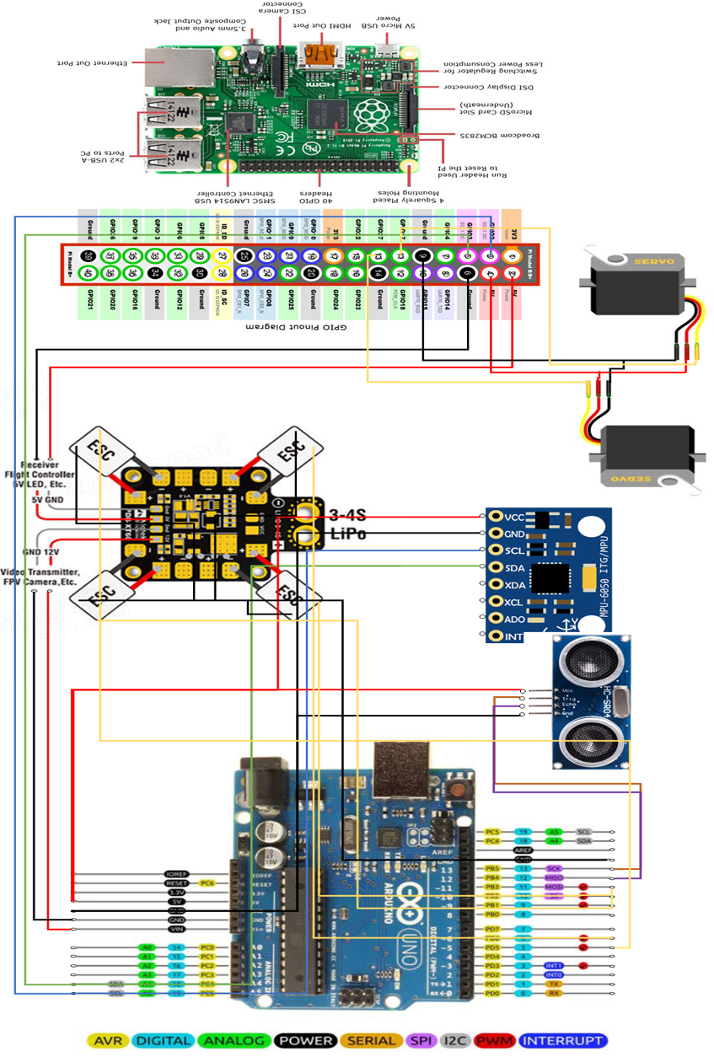
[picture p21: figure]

Abbildung 20: Beadboard

## 7.2 Schematic

Nach einigen erfolgten Diskussionen im Projektteam fiel die Entscheidung auf das Anfertigen einer Platine im Stile eines PCBs. Der ausschlaggebende Faktor für diese Entscheidung war die Prämisse, den Schaltkreis und die letztendliche Verkabelung so einfach wie möglich zu halten, um die Fehleranfälligkeit zu reduzieren.

Die gesamte Konstruktionsarbeit für die Platine erfolgte mit dem Programm Eagle von Autodesk. Der Vorteil bei der Benutzung dieses Programms besteht darin, dass im ersten Schritt die Logik komplett unabhängig vom späteren Layout erstellt werden kann. Die entsprechenden Komponenten (Schraubklemmen) des Herstellers Würth werden aus dessen Onlinebibliothek in Eagle importiert und per Drag & Drop auf das Bearbeitungsfeld gezogen. Im nächsten Schritt werden mithilfe von Labels die einzelnen Leiterbahnen so definiert, dass GND und VCC (Ground und Power) mit der richtigen Logik verbunden sind.

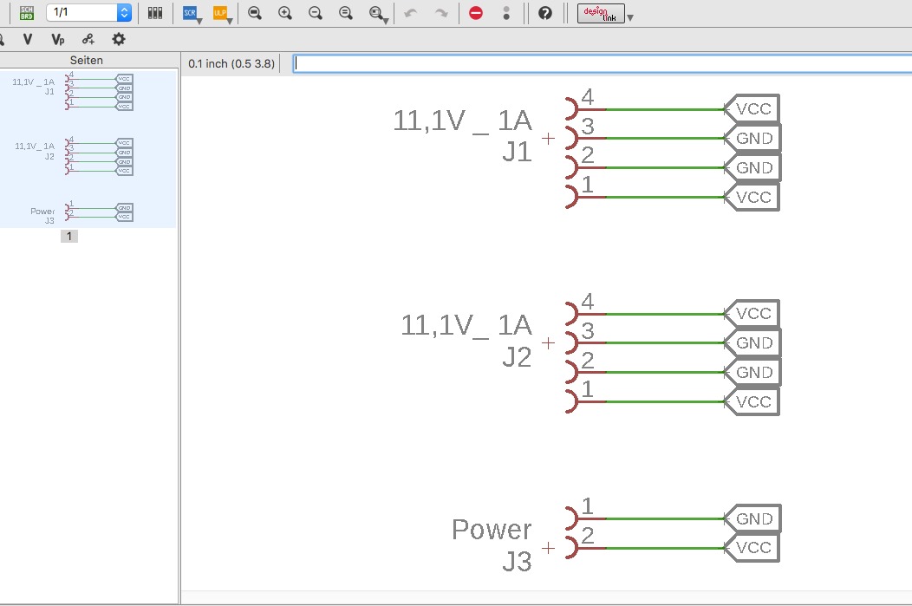
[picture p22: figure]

Abbildung 21: PCB-Schematic

## 7.3 Board

Nach der Erstellung der schematischen Zeichnung gelangt man durch die Aktivierung einer Schaltfläche in die Board-Layout-Ansicht. Hier kann man nun die vorher definierten Komponenten so platzieren, wie es das Projekt erfordert. Die Abmessungen des Boards werden nach Bedarf festgelegt und die Komponenten so angeordnet, dass bei den späteren Schritten des Lötens und der Verkabelung noch genug Arbeitsraum vorhanden ist. Das ist insbesondere bei Projekten wichtig, wo die Platine vielen Tests unterzogen wird und die Verbindungen oft gelöst und wieder befestigt werden müssen.

Im letzten Schritt wird das Layout und die Dicke der Leiterbahnen festgelegt. Da die Platine mithilfe eines Fräsers erstellt wird, ist es wichtig in der Darstellung des Boards nur einen Layer (Ebene) auszuwählen. Bei einfachen Projekten, bei denen man die Funktion „Autorouting“ verwenden will, also die automatische Verbindung der Komponenten, ist das umso wichtiger. Wird das nicht korrekt definiert, kann es vorkommen, dass die Leiterbahnen sich überscheiden, da das Programm von mehreren Layern ausgeht. Sind alle Einstellungen korrekt vorgenommen, inklusive der Dicke der Leiterbahnen, kann die Autoroutingfunktion verwendet werden und das für den Fräser benötigte monochrome Bild exportiert werden.

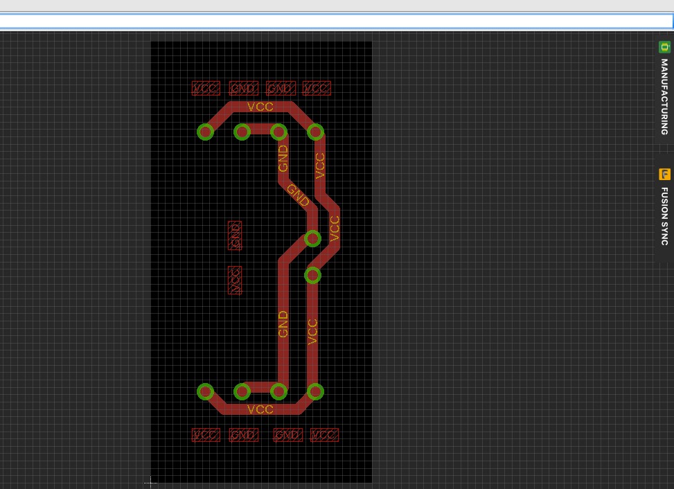
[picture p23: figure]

Abbildung 22: PCB-Board

Leider konnte das PDB der Last nicht standhalten und brannte nach wenigen Tests durch, weshalb Ersatz gekauft werden musste.

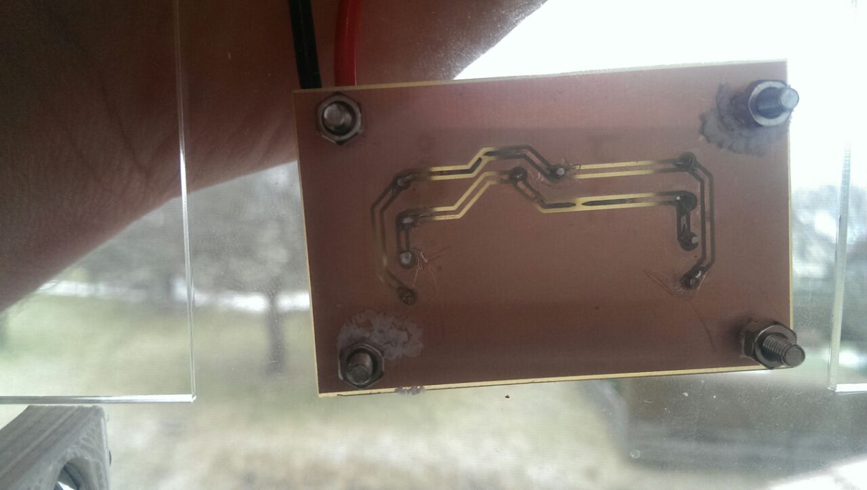
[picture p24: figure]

Abbildung 23: Durchgebranntes PCB

# 9. Lessons Learned

- Be realistic! Only do projects where scope, resources and time fits together.
- So, don’t be emotional! Don’t try thinks which are utopic only because you like them.
- As PM give clearly defined and small tasks. So that a team member can work step by step and not got overwhelmed.
- Everyone who completes a task has to document his doings and achieves instantly.

Systems Engineering 10

Embedded Systems 10

Kurzfassung VII

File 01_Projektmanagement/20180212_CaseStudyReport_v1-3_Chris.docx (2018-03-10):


Mohne – Mobile Drohne

Abschlussbericht

Entwicklung eines autonomen Fahrzeuges für extraterrestrische Erkundungsmissionen

Eingereicht bei:

Fachhochschule Kufstein Tirol Bildungs GmbH

Studiengang Smart Products & Solutions

Verfasser:

Christian Gruber

Abgabedatum:

02.03.2018

# List of Figures

# List of Tables

# List of Abbreviation

IoT | Internet of Things
GM | Geschäftsmodell
GMI | Geschäftsmodell-Innovation
DBT | Digital Business Transformation
IT | Informationstechnik
EY | Ernst & Young
ROI | Return on Investment
KPI | Key Performance Indicator
MIT | Massachusetts Institute of Technologie
IKT | Informations- und Kommunikationstechnik
HR | Human Resources
BDI | Bundesverband der Deutschen Industrie e.V.
CEO | Chief Executive Officer
F&E | Forschung und Entwicklung

# Abstract (max. 1 page)

Summarize and descirbe the project

Management concept?

What concept was applied?

How was it fabricated?

Performance in the tracks?

Lessons learned?

# 1. System Beschreibung

## 1.1 Mechanisches Konzept

Die Mohne ist ein sogenannter „Hybrid-Quadrocopter“, der sowohl zum Fahren als auch zum Fliegen konzipiert ist. Durch diese Hybrid-Nutzung ergeben sich große Vorteile. Auf dem Boden spart der Roboter Energie (im Verhältnis zur Fortbewegung in der Luft), während er in der Luft auch meterhohe Hindernisse überwinden kann. Nachfolgend wird das mechanische Konzept beider Varianten näher erläutert sowie und in Abbildung 5 veranschaulicht.

### 1.1.1 Flugmodus

Die Mohne gehört zur Gruppe der Quadrocopter, bestehend aus vier Motoren die in H-Konfiguration angeordnet sind. Bei der H-Konfiguration sind die vier Motoren in 45° zur Flugrichtung versetzt, wobei der Abstand vom Kreuzmittelpunkt zu den einzelnen Motoren immer gleich groß ist.

Vier Propeller sind fest an den Motoren montiert und erzeugen den Auftrieb der Drohne, welcher sich über die Drehzahl der einzelnen Motoren verändern lässt. Übersteigt die durch die sich drehenden Propeller erzeugte Auftriebskraft die Anziehungskraft der Erde bzw. des Mars, so beginnt die Drohne zu schweben. Eine Erhöhung bzw. Verringerung der Drehzahl hat ein Steigen bzw. ein Sinken der Drohne zufolge.

Dadurch ergibt sich ein relativ einfacher mechanischer Aufbau, in dem es außer den Rotoren der Motoren keine weiteren beweglichen Teile für den Flugmodus gibt.

Überkreuz liegende Rotoren drehen dabei in die gleiche Richtung (Abbildung 1) und heben somit das um die Mitte der Drohne übertragene Drehmomente auf.

Bei exakt gleicher Drehgeschwindigkeit aller Propeller und keinen äußeren Störeinflüssen, steht die Drohne also exakt lotrecht über dem Boden. Dies eliminiert die Notwendigkeit einer Gierstabilisierung.

Um ein nach vorne fliegen zu ermöglichen, drehen sich die vorderen Rotoren langsamer als die hinteren, was ein nach vorne abkippen der Drohne zur Folge hat (Abbildung 2). Entsprechend wird ein nach hinten fliegen ermöglicht, indem die hinteren Rotoren langsamer als die vorderen drehen (Abbildung 3).

Abbildung 1: Quadrocopter: Motordrehrichtung

Abbildung 2: Quadrocopter: Vorwärtsbewegung

Abbildung 3: Quadrocopter: Rückwärtsbewegung

### 1.1.2 Fahrmodus

Um mit der Mohne auch fahren zu können, wurde eine Radaufhängung mit Achsen an die Drohne montiert. Allerdings werden dabei die Räder nicht von einem Motor betrieben, stattdessen wird die Schubleistung von den Propellern der Mohne erzeugt. Die hinteren Tragflächen des Quadrocopters lassen sich im Fahrmodus über Zahnräder um nahezu 90° nach vorne und hinten verstellen (Abbildung 4). In diesem Modus drehen sich nur die hinteren Propeller, wodurch ein Vorschub ähnlich wie bei einem Flugzeug bzw. Schiff erzeugt wird. Ein Abbremsen erfolgt indem die Propeller auf Umkehrschub gestellt werden. Sie erzeugen so einen nach vorne gerichteten Schub. Die Verstellung erfolgt dabei elektrisch.

+90°

-90°

Abbildung 4: Tragfläche mit Propeller: Verstellbar um +90° und -90°

### 1.1.3 Funktionsprinzip der Propeller

Wichtig für das Verständnis des Funktionsprinzips der Drohne ist, dass man sich grob phänomenologisch die Wirkungsweise von Propellern veranschaulicht, weil sich schon aus recht simplen Überlegungen Hinweise darauf ergeben, wie die Propeller sinnvollerweise ausgelegt werden müssen. Die Wirkungsweise eines Propellers, dessen Aufgabe sowohl im Flug- als auch im Fahrmodus darin besteht eine Drehleistung von 2πQn optimal in eine Schubleistung T_(v_A) umzusetzen, kann aus zwei Anschauungen gewonnen werden, die dann in jeweils unterschiedlichen Berechnungsmodellen münden:

- Impulsbetrachtung: Um einen Schub T nach vorne bzw. nach oben zu erzeugen, muss der Propeller die Luft nach hinten bzw. nach unten beschleunigen. Die Änderung des Impulses entspricht dabei dem Propellerschub. Die Theorie, die auf diesem Modell aufbaut, ist die Strahltheorie.
- Tragflügelbetrachtung: Die Wirkungsweise eines Propellers entspricht der eines Tragflügels. Der Auftrieb entspricht dabei dem Schub, der Widerstand dem Moment. Das Tragflügelmodell erklärt die Propellerwirkung an den einzelnen Flügelschnitten und ist als Traglinentheorie (nur radiale Diskretisierung) oder Tragflächentheorie bekannt.

Aus diesen beiden Wirkungsweisen lassen sich schon einige grundlegende Dinge qualitativ ableiten, ohne dass genaue mathematische Begründungen nötig sind. Die Auslegung der Propeller erfolgt in Kapitel …???

Motor

+

Propeller

Motor

+

Propeller

Motor

+

Propeller

Motor

+

Propeller

Rad

Rad

Rad

Rad

Servo

Servo

Abbildung 5: Quadrocopter: Mechanisches Konzept

## 1.2 Sensing Concept

Um die Mohne autonom fliegen bzw. fahren zu lassen und Hindernisse und Ziele zu erkennen, wurde eine Kamera und ein Ultraschallsensor verbaut. Nachfolgend werden beide Sensoren näher beschrieben und das System im Gesamtkontext betrachtet.

### 1.2.1 Picamera

### 1.2.2 Ultraschallabstandssensor

Mit dem Ultraschallabstandssensor (Abbildung 6) kann man mittels eines Ultraschalllautsprechers und eines Mikrofons den Abstand berührungslos zu einem Objekt messen. Das Prinzip (Abbildung 7) basiert darauf, dass die Schallgeschwindigkeit in der Luft bei gleichbleibender Temperatur nahezu konstant bleibt - bei 20°C beträgt sie 343,2m/s. Aus diesem Fakt kann man die Abstandsmessung in eine Zeitmessung überführen, welche dann von Mikrokontrollern einfach übernommen werden kann.


Abbildung 6: Ultraschallabstandssensor

Abbildung 7: Funktionsprinzip Ultraschallabstandssensor

### 1.2.3 Gesamtsystem (big picture)

Die unter Punkt 1.2.1 und 1.2.2 beschriebenen Sensoren unterstützen den Hybrid-Quadrocopter sich in seiner Umgebung zurechtzufinden und sich autonom fortzubewegen, Ziele zu erkennen und Hindernisse gekonnt zu überfliegen. Die Picamera dient dazu ein Ziel zu erkennen und dieses anzusteuern, mit Hilfe des Ultraschallsensors kann ein Hindernis erkannt werden, woraufhin in den Flugmodus gewechselt wird, um das Hindernis zu überfliegen und um nach einer bestimmten Zeit x zu landen und wieder in den Fahrmodus zu wechseln. Wie in Abbildung 8 veranschaulicht sind dabei beide Sensoren mit einem Microcontroller verbunden.

Abbildung 8: Quadrocopter: Sensorkonzept

Controller

Kamera

Ultraschallsensor

# 2. Materialien und Methoden

Um das Projekt zu realisieren und die Mohne zu entwickeln, wurde Seitens des Auftraggebers verschiedene Materialien und Werkzeugmaschinen sowie ein Budget von 40€ zur Verfügung gestellt.

Es gab viele Faktoren, die dazu beitrugen, wie dieser Hybrid-Quadrocopter konstruiert werden sollte. Das Team musste zuerst berücksichtigen, dass die Drohne Testflüge absolvieren musste, von denen sie gegebenenfalls nicht in einem Stück zurückkehrt. Hinzu kam, dass das Gewicht der für die Herstellung der Drohne verwendeten Materialien sorgfältig geprüft werden musste, damit das Gewichtslimit und auch die Größe für den Wettbewerb nicht überschritten wurde. Schließlich musste das Design auf eine Art und Weise erstellt werden, welches leicht mit den zur Verfügung stehenden Materialien und Werkzeugmaschinen umgesetzt werden konnte. Zudem musste das Design die Elektronik vor Wasser schützen. Aufgrund des entscheidensten Faktors, die für die Produktion zur Verfügung stehenden Zeit, wurde entschieden, Lasercutten, 3D-Druck, Schneiden, Schleifen, Fräsen und verbinden mit Schrauben zu verwenden. Dieser Prozess wurde als am schnellsten und am leichtesten reproduzierbar bestimmt, falls erforderlich. Der erste Schritt in diesem Prozess war das Design der Drohne zu entwerfen. Dafür wurde die in Abschnitt 2.3.1 beschriebene CAD-Software Autodesk Inventor verwendet. Im nächsten Schritt wurde bestimmt, wie die einzelnen Komponenten hergestellt und welche Materialen dafür verwendet werden sollten. Komponenten wir Arduino, Raspberry Pi und Sensoren wurden zur Verfügung gestellt. Da jedoch kein Breadboard verwendet werden durfte, wurde mit Hilfe der in 2.3.2 beschriebenen Software ein Leiterplatten-Layout erstellt, welches mit Hilfe einer Fräsmaschine gefertigt wurde.

In diesem Kapitel werden die bereitgestellten Materialien aufgelistet, die verfügbaren Maschinen vorgestellt sowie eine Vorstellung der verwendeten Software.

## 2.1 Materialien

Material | Maße in mm (l x b x h)
Holz | 800 x 600 x 3,8
Plexiglas | 600 x 400 x 3

## 2.2 Manufacturing Technologies

Werkzeug / Maschine

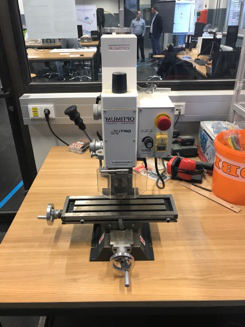
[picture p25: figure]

Bohr-Fräsmaschine Optimum BF 16 Vario


Schraubstock


Schleifmaschine Holzstar BTS 150


Bandsäge Metabo BAS 317 Precision


Digitaler Messschieber Scala 150mm


Ultimaker 2 3D-Drucker
Ultimaker 3 Dual Extruder 3D-Drucker


Fräsmaschine Roland SRM-20


Lötstation Weller WS 81


Lasergravierer Trotec Speedy 360


Metallsäge


Schraubenzieher


Schraubenschlüssel

## 2.3 Software Tools

Um das Projekt zu realisieren, wurden zweierlei verschiedene Softwareprogramme verwendet. Zum einen wurde Autodesk Inventor Professional verwendet, um ein 3D CAD-Modell der Mohne zu erstellen, zum anderen wurde für die Konstruktion der Leiterplatte das Programm EAGLE der Firma Autodesk verwendet. Beide Programme werden nachfolgend kurz beschrieben.

### 2.3.1 Autodesk Inventor Professional

Autodesk Inventor ist eine von Autodesk entwickelte 3D-CAD-Software für die Volumenmodellierung, mit der digitale 3D-Prototypen erstellt werden können. Es wird für 3D-Konstruktion, Design-Kommunikation, Werkzeugherstellung und Produktsimulation verwendet. Diese Software ermöglicht es Benutzern, genaue 3D-Modelle zu erstellen, um Produkte zu entwerfen, zu visualisieren und zu simulieren, bevor sie gebaut werden.

Die Software ermöglicht zudem 2D- und 3D-Daten in eine einzige Designumgebung zu integrieren und so eine virtuelle Darstellung des Endprodukts zu erstellen, mit der die Form, Passform und Funktion des Produkts vor dem Bau validieren werden kann. Autodesk Inventor enthält leistungsstarke parametrische, direkte Bearbeitungs- und Freiform-Modellierungswerkzeuge sowie Multi-CAD-Übersetzungsfunktionen und DWG Zeichnungen nach Industriestandard, wodurch Entwicklungskosten gesenkt, schnellere Time-to-Market realisiert und großartige Produkte entwickelt werden können.

### 2.3.2 Autodesk EAGLE

EAGLE ist eine skriptfähige EDA-Anwendung (Electronic Design Automation) mit Schaltplan-Erfassung, Leiterplatten-Layout, Auto-Router und CAM-Funktionen (Computer Aided Manufacturing). EAGLE steht dabei für Easy Applicable Grafischer Layout-Editor.

Das Programm bietet eine grafische Benutzeroberfläche und ein Menüsystem mit mehreren Fenstern für die Bearbeitung, das Projektmanagement und die Anpassung der Schnittstellen- und Designparameter. Das System kann über Maus, Tastaturkürzel oder durch Eingabe bestimmter Befehle in einer eingebetteten Befehlszeile gesteuert werden. Mehrere Wiederholungsbefehle können zu Skriptdateien kombiniert werden. Es ist auch möglich, Entwurfsdateien unter Verwendung einer EAGLE-spezifischen objektorientierten Programmiersprache zu untersuchen.

### 2.3.3 Arduino IDE

Arduino bringt eine eigene integrierte Entwicklungsumgebung (IDE) mit, die auf Wiring IDE basiert. Dabei handelt es sich um eine Java-Anwendung, die für die gängigen Plattformen Windows, Linux und MacOS kostenlos verfügbar ist. Sie basiert auf der IDE von Processing, einer auf die Einsatzbereiche Grafik, Simulation und Animation spezialisierten Entwicklungsumgebung. Die Arduino-IDE bringt einen Code-Editor mit und bindet gcc als Compiler ein. Zusätzlich werden die avr-gcc-Library und weitere Arduino-Librarys eingebunden, die die Programmierung in C und C++ stark vereinfachen. Arduino kann verwendet werden, um eigenständige interaktive Objekte zu steuern oder um Softwareanwendungen auf Computern zu interagieren (z.B. Adobe Flash, Processing, Max/MSP, Pure Data, diverse Skriptsprachen, etc.)

Für ein funktionstüchtiges Programm genügt es, zwei Funktionen zu definieren:

- setup() – wird beim Start des Programms (entweder nach dem Übertragen auf das Board oder nach Drücken des Reset-Tasters) einmalig aufgerufen, um z. B. Pins als Eingang oder Ausgang zu definieren.
- loop() – wird durchgehend immer wieder durchlaufen, solange das Arduino-Board eingeschaltet ist.

### 2.3.4 Raspbian

Raspbian ist ein kostenloses Betriebssystem, das auf Debian basiert und für die Raspberry Pi-Hardware optimiert ist. Ein Betriebssystem ist die Menge der grundlegenden Programme und Dienstprogramme, die den Raspberry Pi laufen lassen. Raspbian bietet jedoch mehr als ein reines Betriebssystem: Es enthält mehr als 35.000 Pakete, vorkompilierte Software in einem schönen Format für die einfache Installation auf dem Raspberry Pi. Dieses Betriebssystem basiert auf einem Debian-9-System (Debian Stretch) der ARM-hard-float-Architektur (armhf) mit Anpassungen an den Befehlssatz für den ARMv6-Prozessor. Als grafische Oberfläche wird LXDE vorkonfiguriert. Das etwa 3 GB große Image kann auf SD-Karten mit 4 GB oder mehr übertragen werden. Nach dem Bootvorgang kann die Größe der Raspbian-Partition auf die gesamte SD-Karte erweitert werden. Die Raspberry Pi Foundation erstellt auf Basis der Raspbian-Distribution ein eigenes Raspbian-Image mit passender Firmware für die Raspberry-Pi-Modelle, es wird daher empfohlen, die Distribution immer von der Raspberry Pi Foundation zu beziehen.

### 2.3.5 Python

Das Pi im Namen des Raspberry Pi leitet sich von der Programmiersprache Python ab: Die Schöpfer des Minicomputers wollten damit zum Ausdruck bringen, dass diese moderne Skriptsprache besonders zu empfehlen ist.

Python ist eine universelle, üblicherweise interpretierte höhere Programmiersprache. Sie hat den Anspruch, einen gut lesbaren, knappen Programmierstil zu fördern. So werden beispielsweise Blöcke nicht durch geschweifte Klammern, sondern durch Einrückungen strukturiert.

Python unterstützt mehrere Programmierparadigmen, z. B. die objektorientierte, die aspektorientierte und die funktionale Programmierung. Ferner bietet es eine dynamische Typisierung. Wie viele dynamische Sprachen wird Python oft als Skriptsprache genutzt.

Die Sprache hat ein offenes, gemeinschaftsbasiertes Entwicklungsmodell, das durch die gemeinnützige Python Software Foundation, die de facto die Definition der Sprache in der Referenzumsetzung CPython pflegt, gestützt wird.

Wegen ihrer klaren und übersichtlichen Syntax gilt Python als einfach zu erlernen. Sie besitzt eine umfangreiche Standardbibliothek und zahlreiche Pakete im Python Package Index.

Zur Standardinstallation von Python gehört eine integrierte Entwicklungsumge- bung namens IDLE.

Raspbian bringt die Python-Entwicklungsumgebung IDLE bereits vorinstalliert auf dem Desktop mit, sodass bei Bedarf direkt losgelegt werden kann.

IDLE besteht im Wesentlichen aus drei Komponenten:

- Die Python-Shell: Beim Starten von IDEL öffnet sich zuerst das Python-Shell- Fenster. Die Shell ist eine Anwendung, mit der Sie direkt mit dem Python-In- terpreter kommunizieren können: Sie können auf der Kommandozeile einzel- ne Python-Anweisungen eingeben und ausführen lassen. Ein Python-Pro- gramm, das eine Bildschirmausgabe liefert, gibt diese in einem Shell-Fenster aus.
- Der Programmeditor: Das ist eine Art Textverarbeitungsprogramm zum Schreiben von Programmen. Sie starten den Programmeditor vom Shell-Fens- ter aus (FILE|NEW WINDOW).
- Der Debugger: Er dient dazu, den Lauf eines Programms zu kontrollieren, um logische Fehler zu finden.

### 2.3.6 Samba

Sabba ist ein freies Programmpaket, das es ermöglicht Windows-Funktionen wie die Datei- und Druckdienste unter anderen Betriebssystemen zu nutzen und die Rolle eines Domain Controllers anzunehmen. Es implementiert hierfür unter anderem das Server Message Block/Common Internet File System-Protokoll (SMB/CIFS-Protokoll).

Da die Software unter der General Public Licence (GPL) kostenfrei verfügbar ist, wird sie als Alternative zu Microsoft-Windows-Server-Betriebssystem eingesetzt.

### 2.3.7 Maschinensoftware

# 3. System Life Cycle

Im Rahmen des Projekts Mars Explorer sollen die gewonnenen Erkenntnisse aus den Lehrveranstaltungen Systems Engineering, Embedded Systems und Projektmanagement Anwendung finden sowie eine Fablab Umgebung, mechanische und elektronische Komponentenfertigung und Platinenfertigung kennengelernt werden.

## 3.1 Systemanforderungen

### 3.1.1 Zweck

Das Ziel des Projekts ist, mit den bereitgestellten Komponenten, Materialien, Maschinen und Budget, die Entwicklung eines autonomen Fahrzeuges, welches für extraterrestrische Erkundungsmissionen geeignet ist. Die Eignung wird dabei auf fünf Teststrecken überprüft. Die Anforderungen an das Fahrzeug sind folgende:

- Unbeschadeter Sturz aus einer maximalen Fallhöhe von 0,5 m
- Schutz vor Staub und Wasser
- Abmessungen für den Transport in der Rakete:
  - Länge < 65 cm
  - Breite < 48 cm
  - Höhe < 30 cm
- Gewicht des Fahrzeuges:
  - mRover < 10 kg (Erde)
  - mRover < 4,5 kg (Mars)
- Fortbewegung frei wählbar, jedoch autonom
- Budget: 40 €

### 3.1.2 Ziel

Das Projekt soll zu einem autonomen Hybrid-Quadrocopter führen, welcher die unter 3.6 beschriebenen Tracks überwinden kann, indem er zwischen Fahr-und Flugmodus wechselt und seine Umgebung mittels Ultraschallsensor und Kamera erkennt und entsprechend auf unterschiedliche Situationen reagiert. Herzstück des Fahrzeugs ist ein Raspberry Pi sowie ein Arduino, welche Daten empfangen, verarbeiten und Befehle weiterleiten.

Teilziele für das Projekt sind:

- Konstruktion und Fertigung des Chassis
- Drehmechanismus der hinteren Tragflächen konstruieren und fertigen um zwischen Fahr-und Flugmodus zu wechseln
- Platine konstruieren und fertigen
- Programmierung der Motorsteuerung incl. ESC Kalibrierung um die Voraussetzung für das Fliegen zu schaffen
- Autonomer Modus mit Hilfe von Sensoren realisieren (Programmierung für Ultraschallsensor und Kamera)
- Steuerungscode und PIC-Regelung um den Quadrocopter stabil in der Luft zu halten

### 3.1.3 Einschränkungen

Das Ein- und Ausschalten erfolgt im manuellen Modus, während dem Fliegen und Fahren agiert die Mohne manuell. Der Abstand zum Boden wird nicht gemessen. Das Überwinden von Hindernissen erfolgt, indem vom Fahrmodus in den Flugmodus gewechselt wird und nach einer vorher eingestellten Zeit wieder in den Fahrmodus übergegangen wird.

Das System muss nur unter guten Wetterbedingungen und auf vorgegebenen Kursen funktionieren, weshalb nur ein geradeausfahren- fliegen realisiert wird.

## 3.2 Designalternativen

Um über ein Design für dieses Projekt zu entscheiden, mussten bestimmte einschränkende Faktoren berücksichtigt werden, nämlich die maximale Größe und das maximal zulässige Gewicht das das Fahrzeug haben darf, um noch von der Trägerrakete auf den Mars befördert werden zu können. Auch unter der Voraussetzung, dass die elektronischen Komponenten, die irgendwo innerhalb des Rumpfes eingeschlossen und befestigt werden müssen, vor Staub und Wasser geschützt sein müssen, wurden die Möglichkeiten weiter eingeengt. Das vorgegebene Budget und Zeitlimit sowie die zur Verfügung gestellten Materialien und Maschinen limitierten weitere Möglichkeiten. Nachdem einige Überlegungen und Forschung betrieben wurde wie die einzelnen Hürden der Teststrecken am einfachsten bewältigt werden konnten, wurde entschieden, dass ein Hybrid-Quatrocopter entwickelt werden würde. Auch aufgrund der Tatsache, dass sich Drohnen zunehmender Beliebtheit erfreuen und in immer mehr Einsatzbereichen Anwendung finden wollten wir uns dieser Herausforderung stellen und auf die Konstruktion eines konventionellen Mars-Rovers verzichten.

## 3.3 Model the System

Hybrid-Quadcopter
Actuator
Avionics
Frame
Power Distribution
Motor
Propeller
ESC
Servo
Sensors
Battery
Wires
Power Distribution Board
Computer
Microcontroller
Carrier
Chassis
Rotary mechanismIn der Regel werden für nahezu alle alternativen Designs Modelle entwickelt. Das Modell für die bevorzugte Alternative wird dann erweitert und verwendet, um das System über seinen gesamten Lebenszyklus hinweg zu verwalten. Aufgrund der kurzen Entwicklungszeit wurden keine Modelle für alternative Designs entwickelt. In erster Linie sollen die nachstehenden Modelle auch dazu dienen das System zu beschreiben.

### 3.3.1 System and Subsystem

### 3.3.2 Make or Bye

Motor | Commercially available subsystem
Propeller | Commercially available subsystem
ESC | Commercially available subsystem
Servo | Commercially available subsystem
Sensor | Commercially available subsystem
Microcontroller | Commercially available subsystem
Computer | Commercially available subsystem
Carrier | In-house-design
Chassis | In-house-design
Rotary mechanism | In-house-design
Battery | Commercially available subsystem
Wires | Commercially available subsystem
Power Distribution Board | Commercially available subsystem

### 3.3.3 Communication Model


### 3.3.4 System Architecture

Stromversorgung

(LiPo Akkus)

Servo

Servo

Ultraschallsensor

Kameramodul

Arduino

Motorregler

Motorregler

Motorregler

Motorregler

Motor mit Propeller

Motor mit Propeller

Motor mit Propeller

Motor mit Propeller

Raspberry Pi

WLAN Not-Stopp

### 3.3.5 Functional Decomposition

Function | Pysical Component
Take-off, drive and land | Wheels
Sense objects | Sensors
Navigate | Microcomputer
Produce horizontal thrust and vertical lift | Propeller and wings

### 3.3.6 Failure Mode and Effects Analysis (FMEA)

The procedure used to evaluate the various modes of failure in our drone design takes into consideration the severity, probability of occurrence and detectability for each failure mode as well as the root causes. Based on the values assigned to each category, the risk priority and criticality of each cause are calculated. Our failure analysis focused on four failure modes; mobility, navigation, structural and data acquisition. We determined the key failures modes to be mobility and navigation. In each of these two cases, control system and wiring failure are the root causes with the highest risk priorities and criticalities.

Possible Effect | Root Cause | Potential Indicators | Potential Cause(s) of Failure | Severity | Probability of Occurence | Detectability | Risk Prirority | Criticality
Mobility | dead battery | will not power motor | Battery not charged | 5 | 3 | 1 | 15 | 15
| controls failure | Motors, servos and PID controller failure | Programming error | 5 | 9 | 9 | 405 | 45
| wiring harness connections | will not start or run correctly | Grounding corrosion | 8 | 8 | 9 | 576 | 64
Navigation | Wiring failure | Complete navigation failure | Wiring error | 8 | 7 | 2 | 112 | 56
| Controls Failure | Complete navigation failure | Programming error | 5 | 9 | 9 | 405 | 45
| Object sensing hardware failure | Part damage | Wiring control failure | 5 | 3 | 3 | 45 | 15
| Rotary mechanism failure | Steering failure | Impact on gear | 5 | 5 | 1 | 25 | 25
Structural | Frame cracking | No component support | Impact on frame | 10 | 3 | 4 | 120 | 30
| Engin mount | Engin falls out | Engin mount wear | 2 | 1 | 1 | 2 | 2
Data Acquisition | Camera not working | No video recording | Weather proofing controls/wire | 1 | 5 | 2 | 10 | 5
| Ultrasonic sensor not working | No distance measurement | Weather proofing controls/wire | 1 | 5 | 3 | 15 | 5
| Incorrect wiring | Will not move | Wiring error | 2 | 2 | 4 | 16 | 4
| Controls failure | No/incorrect data | Programming error | 1 | 2 | 5 | 10 | 2

## 3.4 Integrate System Components

## 3.5 Launch the System

### 3.5.1 Timeline


Task | Team Member(s)
Designentscheidung | alle
Chassis konstruieren und fertigen | Duregger, Jungwirth, Gruber
Bilderkennung | Paula, Gruber
Kamerahalterung | Duregger, Jungwirth
Radaufhängung, Achsen und Welle | Duregger, Jungwirth, Gruber
Platinelayout | Möbes
Elektronik | Möbes, Gruber
Servohalterung + Drehmechanismus | Duregger, Jungwirth, Gruber
Motorhalterung | Duregger, Jungwirth, Gruber
Abstandhalter zwischen Platinen | Duregger, Jungwirth, Gruber
ESC Kalibrierung und Motorsteuerung | Möbes, Gruber
Steckverbindung HV Akku und Stromplatine | Möbes
Steuerungscode | Möbes, Paula, Gruber
Projektmanagement und Dokumentation | Wiesmüller
Zusammenbau | Wiesmüller, Gruber
Kostenanalyse | Gruber
Komponentenauswahl und Bestellung | alle
Flugtest und Systemtest | alle

### 3.5.2 Budget


## 3.6 Assess Performance

Während der gesamten Entwicklungsphase wurde die Leistung des Systems immer wieder gemessen und getestet. Diese Messungen waren notwendig um zu verifizieren, dass das System seinen Anforderungen entspricht. Vor allem wurde zu Beginn getestet ob der Rotationsmechanismus wie gedacht funktioniert, was die Basis für den Wechsel zwischen Fahr-und Flugmodus darstellte.

Auch wurden immer wieder Tests durchgeführt um die Bilderkennung und Abstandsmessung sicherzustellen um die autonome Navigation sicherzustellen. Ein weiterer Wichtiger Punkt der immer wieder getestet wurde war die Motorsteuerung um zu gewährleisten, dass sich der Quatrocopter auch fortbewegen kann.

Um letztendlich festzustellen ob das Projekt für einen Einsatz auf dem Mars geeignet ist, sich autonom fortbewegen kann und die Vorstellungen und Wünsche des Auftraggebers erfüllt, mussten 5 Teststrecken absolviert werden, welche nachstehend beschrieben werden.

Track | Abmessungen (l x b) | Oberfläche | Umgebungsbedingung | Ziel
1 | 3m x 1m | Beton | Überdachter Raum | Gerade fahren
2 | 3m x 1m | Beton | Staubsimulation mittels Sprühflaschen | Defektfreie Durchfahrt
3 | 3m x 1m | Holzstufen mit unterschiedlichen Höhen (10cm, 20cm, 30cm, 40cm, 50cm, 60cm) | Überdachter Raum | Hindernisse überwinden
4 | 3m x 1m | Gesteinsbrocken mit unterschiedlicher Höhe (10-60 cm) | Überdachter Raum, Gesteinsbrocken farblich und mit Symbol gekennzeichnet | Track durchqueren, Umfahren der Hindernisse
5 | unbekannt | Unbekannt (Schnee, Eis, Sand, etc.), Gesteinsbrocken mit unterschiedlicher Höhe (10-60cm) | Unter freiem Himmel, Gesteinsbrocken farblich und mit Symbol gekennzeichnet | Überleben

Zudem wurde von den Auftraggebern inspiziert, ob die geforderten Mindestanforderungen an Größe, Gewicht und Stabilität erfüllt wurden.

## 3.7 Results, Conclusion and Recommendations

### 3.7.1 Results

Dieses Projekt dauerte das 4 Wochen und beinhaltete eine Menge Forschung, Tests und Analysen. Zu Beginn des Projekts erstellte das Team erste Projektspezifikationen wie in Abschnitt 3.1 beschrieben, die als Richtlinien für die Mohne dienten. Es wurde eine Überprüfung durchgeführt, um zu sehen, welche Spezifikationen das Projekt erfüllt und welche nicht.

- Die Drohne erfüllte die maximal zulässige Größe und Gewicht
- Der Falltest aus 0,5m Höhe wurde unbeschadet überstanden
- Die Drohne erfüllte die Anforderungen an die Staub- und Wasserfestigkeit
- Die Drohne erfüllte nicht das Budget von 40 € einzuhalten. Das benötigte Budget betrug 46,50 €
- Die Drohne erfüllte die Anforderung des Not-Stopps
- Die Drohne erfüllte die Anforderung seine Umgebung wahrzunehmen
- Der Wechsel zwischen Flug- und Fahrmodus konnte realisiert werden
- Die Drohne konnte geradeaus fahren
- Die Anforderung zu Fliegen wurde nur bedingt erreicht. Obwohl mehrere Flugversuche durchgeführt wurden, konnte nicht umgesetzt werden, dass alle vier Propeller gleichmäßig mit Strom versorgt wurden und die Drohne somit stabil in der Luft stehen konnte. Das Problem wurde erkannt, die dafür benötigte PID-Regelung konnte jedoch aus Zeitgründen nicht umgesetzt werden.
- Aufgrund des vorherigen Problems konnten die Hindernisse nicht überwunden werden

### 3.7.2 Conclusion

Die Endergebnisse zeigten, dass nicht alle Spezifikationen und Ziele, die zu Beginn des Projekts festgelegt wurden, erreicht wurden. Obwohl der vollständig autonome Flug nicht erreicht wurde, hat das Team eine bedeutende Entwicklung hin zu einem kostengünstigen, leichten unbemannten Hybrid-Fahrzeug gemacht, das mit der Implementierung eines Kamerasystems und einem Ultraschallsensor überwacht werden kann. Mehrere Designiterationen wurden abgeschlossen, um ein Fahrzeug zu schaffen, das die Projektziele erfüllen sollte und der endgültige Prototyp zeigt das Potential für den Erfolg der Projektziele. Wie in Abschnitt 3.6 beschrieben, wurden mehrere Tests durchgeführt, um sicherzustellen, dass der entworfene Prototyp erfolgreich fliegen und fahren konnte. Wenn mehr Zeit verfügbar wäre, wäre das Team in der Lage gewesen, ein robusteres Kontrollsystem zu entwerfen, das einen stabilen Flug gewährleisten würde. Insgesamt wurde in diesem Projekt ein unbemanntes Fluggerät vollständig realisiert. Der Hybrid-Quadrocopter zeigte, dass er in der Lage war zu fahren und zu fliegen, aber ihm fehlte die Stabilität. Weitere Iterationen dieses Projekts würden seinen zukünftigen Erfolg sichern.

### 3.7.3 Recommendations

Im Laufe des Projekts wurden mehrere Lektionen gelernt und das Team hat mehrere Empfehlungen. Aus Sicht der Steuerung wären mehr Sensoren hilfreich für mehr Präzision oder Fähigkeiten. Ein weiterer Ultraschallsensor könnte dazu dienen um die Flughöhe zu bestimmen. Die Implementierung weitere Kameramodule könnten eine 360 Grad Wahrnehmung realisieren um Hindernisse zu vermeiden. Auch könnte im nächsten Schritt realisiert werden Kurven zu fahren und zu fliegen. Die Durchführung von Simulationen und Berechnungen würde zu einem effektiveren Design führen.

# 4. Diagrams (obligate)

## 4.1 Use Case Diagram (Anwendungsfalldiagramm)

## 4.2 Structural Model (Strukturmodelle)

Klassendiagramm oder Kompensationsstrukturdiagramme

## 4.3 Interaction Model (Interaktionsmodell)

Sequenzdiagramm (Ludi)

## 4.4 Behavior Model (Verhaltensmodell)

Aktivitätsdiagramme oder Zustandsdiagramme oder Blockdiagramme

# 5. Testing Software (optional)

# 6. Version Control (e.g. Gitlab – obligate)

No source-code report; access to team side

# 7. Design of PCB (obligate) (Max)

## 7.1 Breadboard

## 7.2 Schematic

## 7.3 Board

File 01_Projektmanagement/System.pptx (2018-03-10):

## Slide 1

Servo

Servo

Emergency- Stop

ESC

Motor and Prop

ESC

Motor and Prop

Camera modul

Raspberry Pi

Arduino

ESC

Motor and Prop

Power distribution
(LiPo Akkus)

Ultrasonic sensor

MPU

ESC

Motor and Prop

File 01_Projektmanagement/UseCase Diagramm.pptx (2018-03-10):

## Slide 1

Autonome Fortbewegung

Starten von Mohne

Not Aus von Mohne

Mann

User

Steuerung der Motoren und Servos

Webcam

PiCam

Erkennung von gelernten Formen und Farben

Rückgabe der Werte an die Controller

Satellitenschüssel

USS

Erkennung von Hindernissen

Rückgabe der Werte an die Controller

Satellit

GYRO

Messung der Lage im Raum

Rückgabe der Werte an die Controller

Rechner

Steuerung der Drohne in Abhängigkeit von den Sensorwerten und der Logik

Controller

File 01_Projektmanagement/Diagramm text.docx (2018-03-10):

Beim Start werden zuerst die Servomotoren aktiviert um in den Fahrmodus zu kommen. Nachdem die hinteren zwei Propeller in Stellung sind gibt der Raspberry Pi die Information an den Arduino weiter. Dieser startet die Propeller und die Mohne fährt los. Währenddessen läuft der Ultraschall ständig über den Raspberry Pi um Objekte zu erkennen. Wird eins erkannt wird diese Information an den Arduino geschickt und dieser startet das Bremsprogramm. Ist das Programm fertig teilt dies der Arduino den Raspberry Pi weiter. Dieser startet wieder die Servomotoren für den Flugmodus. Sind die Propeller in der richtigen Position wird diese Information an den Arduino geschickt, damit dieser die Motoren einschaltet. Gleichzeitig läuft der Ultraschall weiter und solange ein Objekt erkannt wird, wird weitergeflogen. Sobald kein Objekt mehr da schickt der Raspberry Pi die Information an den Arduino damit dieser vorwärts fliegt und danach landet. Nach der Landung wird dies dem Pi mitgeteilt und der startet wieder die Servomotoren, damit wieder gefahren wird. Nach dem Positionieren der Propeller wird diese Information wieder an den Arduino geschickt und die Mohne fährt wieder.

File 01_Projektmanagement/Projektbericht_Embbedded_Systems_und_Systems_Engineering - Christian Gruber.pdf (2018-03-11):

### MOHNE – MOBILE DROHNE

### Abschlussbericht

### Entwicklung eines autonomen Fahrzeuges für extraterrestrische

### Erkundungsmissionen

Eingereicht bei:

Fachhochschule Kufstein Tirol Bildungs GmbH

Studiengang Smart Products & Solutions

Verfasser:

Christian Gruber

Abgabedatum:

11.03.2018

II

TABLE OF CONTENTS

List of Figures | V
List of Tables | VI
List of Abbreviation | VII
Abstract | VIII

IV

Switching on and off takes place in manual mode, while flying and driving, the "Mohne"

acts autonomously. The distance to the ground is not measured. Obstacles are overcome

by switching from the driving mode to the flying mode and then returning to the driving

The system only must work in good weather conditions and on given courses, which is

IV

V

LIST OF FIGURES

VI

LIST OF TABLES

VII

LIST OF ABBREVIATION

BDI | Bundesverband der Deutschen Industrie e.V.
CAD | Computer aided design
CEO | Chief Executive Officer
DBT | Digital Business Transformation
EY | Ernst & Young
F&E | Forschung und Entwicklung
GM | Geschäftsmodell
GMI | Geschäftsmodell-Innovation
HR | Human Resources
IKT | Informations- und Kommunikationstechnik
IoT | Internet of Things
IT | Informationstechnik
KPI | Key Performance Indicator
MIT | Massachusetts Institute of Technologie
PDB | Power distribution board
PLA | Polylactide
ROI | Return on Investment
USS | Ultrasonic Sensor

VIII

ABSTRACT

In this project our team had an easy mission. Build a vehicle that can be transported to the

mars and move there autonomous. Just kidding, it was obviously not an easy mission. You

need to know exactly about your resources, know-how and a huge amount of planning.

To get the breath of a chance we setup concrete roles, made an overall plan where we already

saw, our goal of an autonomous drone was hard to reach within time. We decided to mix

traditional and agile project management methods. For the overall planning we setup a mile-

stone plan. The milestones correlated with our agile sprint rota. Within the singe project

phases, we accomplished our tasks agile step by step. Therefore, we used the Kanban board

on github. We tried only to setup tasks that can be done within one sprint.

We thought about several concepts, but we were focused on the task, that the vehicle must

get over a 60cm high obstacle, although the vehicle may only be 60cm long. After a few

“round table meeting”, we decided to build a hybrid drone, which can drive and fly, because

flying could be the easiest way to get over an obstacle.

After the drone was constructed with CAD, we decided to use acrylic glass and 3D printed

PLA as main material. We invented a new mechanism, so that the rear motor mountings

could be turned with two servos. With this mechanism we changed the moving modus be-

tween flying and driving. For power distribution we made a tiny single board to connect all

Controller with the accumulator. As controller we needed the 4 ESCs for the motors, a Rasp-

berry Pi as main unit and an Arduino Uno as fast control unit e.g. for PID regulation.

From the five virtual tracks we had to accomplished, we could only overcome successful

two. So, you can’t really say our mission to mars was successful at this point.

But we laid the foundation for the next project of autonomous driving vehicles and even

more important our team learned a lot. We learned totally new technical aspects, like aviation

and what’s necessary to actual fly. Also, we learned much about project management for

huge projects within no time… that’s not possible within an acceptable quality. Although

we used our methods quite well, we just couldn’t achieve the huge scope we’ve set ourselves

in this limited time. If we have to bring out the most important lesson learned, then we

learned “don’t decide emotionally that you want to do something absolutely, if all rational

measurements say no!”

1

### 1. SYSTEM BESCHREIBUNG

### 1.1 Mechanisches Konzept

Die Mohne ist ein sogenannter „Hybrid-Quadrocopter“, der sowohl zum Fahren als auch

zum Fliegen konzipiert ist. Durch diese Hybrid-Nutzung ergeben sich große Vorteile. Auf

dem Boden spart der Roboter Energie (im Verhältnis zur Fortbewegung in der Luft), wäh-

rend er in der Luft auch meterhohe Hindernisse überwinden kann. Nachfolgend wird das

mechanische Konzept beider Varianten näher erläutert sowie und in Abbildung 5 veran-

schaulicht.

### 1.1.1 Flugmodus

Die Mohne gehört zur Gruppe der Quadrocopter, bestehend aus vier Motoren die in H-Kon-

figuration angeordnet sind. Bei der H-Konfiguration sind die vier Motoren in 45° zur Flug-

richtung versetzt, wobei der Abstand vom Kreuzmittelpunkt zu den einzelnen Motoren im-

mer gleich groß ist.

Vier Propeller sind fest an den Motoren montiert und erzeugen den Auftrieb der Drohne, welcher sich über die Drehzahl der einzelnen Motoren verändern lässt. Übersteigt die durch

die sich drehenden Propeller erzeugte Auftriebskraft die Anziehungskraft der Erde bzw. des

Mars, so beginnt die Drohne zu schweben. Eine Erhöhung bzw. Verringerung der Drehzahl

hat ein Steigen bzw. ein Sinken der Drohne zufolge.

Dadurch ergibt sich ein relativ einfacher mechanischer Aufbau, in dem es außer den Rotoren

der Motoren keine weiteren beweglichen Teile für den Flugmodus gibt.

Überkreuz liegende Rotoren drehen dabei in die gleiche Richtung (Abbildung 1) und heben

somit das um die Mitte der Drohne übertragene Drehmomente auf.

Bei exakt gleicher Drehgeschwindigkeit aller Propeller und keinen äußeren Störeinflüssen,

steht die Drohne also exakt lotrecht über dem Boden. Dies eliminiert die Notwendigkeit

einer Gierstabilisierung. Um ein nach vorne fliegen zu ermöglichen, drehen sich die vorde-

ren Rotoren langsamer als die hinteren, was ein nach vorne abkippen der Drohne zur Folge

hat (Abbildung 2). Entsprechend wird ein nach hinten fliegen ermöglicht, indem die hinteren

Rotoren langsamer als die vorderen drehen (Abbildung 3).

A | B


Abbildung 1: Quadrocopter: Motordrehrichtung

Abbildung 2: Quadrocopter: Vorwärtsbewegung

Abbildung 3: Quadrocopter: Rückwärtsbewegung

3

### 1.1.2 Fahrmodus

Um mit der Mohne auch fahren zu können, wurde eine Radaufhängung mit Achsen an die

Drohne montiert. Allerdings werden dabei die Räder nicht von einem Motor betrieben, statt-

dessen wird die Schubleistung von den Propellern der Mohne erzeugt. Die hinteren Tragflä-

chen des Quadrocopters lassen sich im Fahrmodus über Zahnräder um nahezu 90° nach

vorne und hinten verstellen (Abbildung 4). In diesem Modus drehen sich nur die hinteren

Propeller, wodurch ein Vorschub ähnlich wie bei einem Flugzeug bzw. Schiff erzeugt wird.

Ein Abbremsen erfolgt indem die Propeller auf Umkehrschub gestellt werden. Sie erzeugen

so einen nach vorne gerichteten Schub. Die Verstellung erfolgt dabei elektrisch.


Abbildung 4: Tragfläche mit Propeller: Verstellbar um +90° und -90°

### 1.1.3 Funktionsprinzip der Propeller

Wichtig für das Verständnis des Funktionsprinzips der Drohne ist, dass man sich grob phä-

nomenologisch die Wirkungsweise von Propellern veranschaulicht, weil sich schon aus recht simplen Überlegungen Hinweise darauf ergeben, wie die Propeller sinnvollerweise

ausgelegt werden müssen. Die Wirkungsweise eines Propellers, dessen Aufgabe sowohl im

Flug- als auch im Fahrmodus darin besteht eine Drehleistung von 2πQn optimal in eine

Schubleistung TvA
umzusetzen, kann aus zwei Anschauungen gewonnen werden, die dann

in jeweils unterschiedlichen Berechnungsmodellen münden:

4

- Impulsbetrachtung: Um einen Schub T nach vorne bzw. nach oben zu er-

zeugen, muss der Propeller die Luft nach hinten bzw. nach unten beschleunigen. Die Änderung des Impulses entspricht dabei dem Propellerschub. Die

Theorie, die auf diesem Modell aufbaut, ist die Strahltheorie.

- Tragflügelbetrachtung: Die Wirkungsweise eines Propellers entspricht der

eines Tragflügels. Der Auftrieb entspricht dabei dem Schub, der Widerstand

dem Moment. Das Tragflügelmodell erklärt die Propellerwirkung an den ein-

zelnen Flügelschnitten und ist als Traglinentheorie (nur radiale Diskretisie-

rung) oder Tragflächentheorie bekannt.

Aus diesen beiden Wirkungsweisen lassen sich schon einige grundlegende Dinge qualitativ

ableiten, ohne dass genaue mathematische Begründungen nötig sind.

Motor + Propeller; Rad; Servo

Abbildung 5: Quadrocopter: Mechanisches Konzept

### 1.2 Sensing Concept

Um die Mohne autonom fliegen bzw. fahren zu lassen und Hindernisse und Ziele zu erken-

nen, wurde eine Kamera und ein Ultraschallsensor verbaut. Nachfolgend werden beide Sen-

soren näher beschrieben und das System im Gesamtkontext betrachtet.

5

### 1.2.1 Picamera

Mit der Kamera sollen vorher definierte Formen und Farben erkannt warden. Die Rückga-

bewerte an den Raspberry Pi sollen in der Logik die vorgesehene Funktion auslösen. Bei-

spiele hierfür sind markierte Hindernisse und das Ziel. Anbei ein Auszug an angelernten

Formen und Farben, hier ist auch das vorgegebene rote Quadrat enthalten. Die Exakte größe

hat für uns keine Rolle gespielt, da wir in der logic Ecken und Kanten zählen haben lassen

und Farben erkennen.


Abbildung 6: Bild zum Anlernen von Formen und Farben

6

### 1.2.2 Ultraschallabstandssensor


Mit dem Ultraschallabstandssensor Abbildung 7: Ultraschallsensor (USS) kann man mittels

eines Ultraschalllautsprechers und eines Mikrofons den Abstand berührungslos zu einem

Objekt messen. Das Prinzip | Abbildung 8: Wirkprinzip USS | basiert darauf, dass die Schall-

geschwindigkeit in der Luft bei gleichbleibender Temperatur nahezu konstant bleibt - bei

20°C beträgt sie 343,2m/s. Aus diesem Fakt kann man die Abstandsmessung in eine Zeit-

messung überführen, welche dann von Mikrokontrollern einfach übernommen werden kann.


### 1.2.3 Gesamtsystem (big picture)

Die unter Punkt 1.2.1 und 1.2.2 beschriebenen Sensoren unterstützen den Hybrid-Quadroco-

pter sich in seiner Umgebung zurechtzufinden und sich autonom fortzubewegen, Ziele zu

erkennen und Hindernisse gekonnt zu überfliegen. Die Picamera dient dazu ein Ziel zu er-

kennen und dieses anzusteuern, mit Hilfe des Ultraschallsensors kann ein Hindernis erkannt

werden, woraufhin in den Flugmodus gewechselt wird, um das Hindernis zu überfliegen und

um nach einer bestimmten Zeit x zu landen und wieder in den Fahrmodus zu wechseln. Wie

Abbildung 7: Ultraschallsensor (USS)

Abbildung 8: Wirkprinzip USS

7

in Abbildung 9: Quadrocopter: Sensorkonzept veranschaulicht sind dabei beide Sensoren

mit einem Microcontroller verbunden.

### 2. MATERIALIEN UND METHODEN

Um das Projekt zu realisieren und die Mohne zu entwickeln, wurde Seitens des Auftragge-

bers verschiedene Materialien und Werkzeugmaschinen sowie ein Budget von 40€ zur Ver-

fügung gestellt.

Es gab viele Faktoren, die dazu beitrugen, wie dieser Hybrid-Quadrocopter konstruiert wer-

den sollte. Das Team musste zuerst berücksichtigen, dass die Drohne Testflüge absolvieren

musste, von denen sie gegebenenfalls nicht in einem Stück zurückkehrt. Hinzu kam, dass

das Gewicht der für die Herstellung der Drohne verwendeten Materialien sorgfältig geprüft

werden musste, damit das Gewichtslimit und auch die Größe für den Wettbewerb nicht über-

schritten wurde. Schließlich musste das Design auf eine Art und Weise erstellt werden, wel-

ches leicht mit den zur Verfügung stehenden Materialien und Werkzeugmaschinen umge-

setzt werden konnte. Zudem musste das Design die Elektronik vor Wasser schützen. Auf-

grund des entscheidensten Faktors, die für die Produktion zur Verfügung stehenden Zeit,

wurde entschieden, Lasercutten, 3D-Druck, Schneiden, Schleifen, Fräsen und verbinden mit

Schrauben zu verwenden. Dieser Prozess wurde als am schnellsten und am leichtesten re-

produzierbar bestimmt, falls erforderlich. Der erste Schritt in diesem Prozess war das Design

Controller

Kamera

Ultraschallsensor

Abbildung 9: Quadrocopter: Sensorkonzept

8

der Drohne zu entwerfen. Dafür wurde die in Abschnitt 2.3.1 beschriebene CAD-Software

Autodesk Inventor verwendet. Im nächsten Schritt wurde bestimmt, wie die einzelnen Kom-

ponenten hergestellt und welche Materialen dafür verwendet werden sollten. Komponenten

wir Arduino, Raspberry Pi und Sensoren wurden zur Verfügung gestellt. Da jedoch kein

Breadboard verwendet werden durfte, wurde mit Hilfe der in 2.3.2 beschriebenen Software

ein Leiterplatten-Layout erstellt, welches mit Hilfe einer Fräsmaschine gefertigt wurde.

In diesem Kapitel werden die bereitgestellten Materialien aufgelistet, die verfügbaren Ma-

schinen vorgestellt sowie eine Vorstellung der verwendeten Software.

### 2.1 Materialien

Tabelle 1: Verfügbare Materialien

Material | Maße in mm (l x b x h)
Holz | 800 x 600 x 3,8
Plexiglas | 600 x 400 x 3

### 2.2 Manufacturing Technologies

Tabelle 2: Verfügbare Maschinen und Werkzeuge

Werkzeug / Maschine

Bohr-Fräsmaschine Optimum BF 16 Vario

Schraubstock

9


Schleifmaschine Holzstar BTS 150

Bandsäge Metabo BAS 317 Precision

Digitaler Messschieber Scala 150mm

Ultimaker 2 3D-Drucker

Ultimaker 3 Dual Extruder 3D-Drucker

Fräsmaschine Roland SRM-20

10

Lötstation Weller WS 81


Lasergravierer Trotec Speedy 360

Metallsäge

Schraubenzieher

Schraubenschlüssel

### 2.3 Software Tools

Um das Projekt zu realisieren, wurden zweierlei verschiedene Softwareprogramme verwen-

det. Zum einen wurde Autodesk Inventor Professional verwendet, um ein 3D CAD-Modell

11

der Mohne zu erstellen, zum anderen wurde für die Konstruktion der Leiterplatte das Pro-

gramm EAGLE der Firma Autodesk verwendet. Beide Programme werden nachfolgend kurz

beschrieben.

### 2.3.1 Autodesk Inventor Professional

Autodesk Inventor ist eine von Autodesk entwickelte 3D-CAD-Software für die Volumen-

modellierung, mit der digitale 3D-Prototypen erstellt werden können. Es wird für 3D-Kon-

struktion, Design-Kommunikation, Werkzeugherstellung und Produktsimulation verwendet.

Diese Software ermöglicht es Benutzern, genaue 3D-Modelle zu erstellen, um Produkte zu

entwerfen, zu visualisieren und zu simulieren, bevor sie gebaut werden.

Die Software ermöglicht zudem 2D- und 3D-Daten in eine einzige Designumgebung zu in-

tegrieren und so eine virtuelle Darstellung des Endprodukts zu erstellen, mit der die Form,

Passform und Funktion des Produkts vor dem Bau validieren werden kann. Autodesk Inven-

tor enthält leistungsstarke parametrische, direkte Bearbeitungs- und Freiform-Modellierungswerkzeuge sowie Multi-CAD-Übersetzungsfunktionen und DWG Zeichnungen nach

Industriestandard, wodurch Entwicklungskosten gesenkt, schnellere Time-to-Market reali-

siert und großartige Produkte entwickelt werden können. Somit haben wir die “Mohne” zu-

nächst vollständig im CAD Programm entworfen, um schnell Anpassungen vornhemen zu

können und gleichzeitig keine Bauteile zu vergessen.


Abbildung 10: Fertiges CAD Model der "Mohne"

12

Tabelle 3: Stückliste des CAD Modells

Name | Anzahl
Chassis mit motorlöcher | 1
Platzhalter Zylinder Klein | 4
Metall Stab M5 | 1
Chassis-2 | 1
Kegelrad | 1
EMax Motor | 4
RaspberryPi2 STEP214 | 1
Metall Stab M5_MIR | 1
StirnradUNDServo_MIR | 1
Propeller | 4
arduino uno | 1
MPU 6050 IMU | 1
Abstandhalter_MPU | 1
LiPo Akku | 1
PDB | 4
Ultrasonic Sensor Halterung | 1
USS | 1
Wheel ALL | 2
Radaufhängung | 4
Wheel ALL1_MIR | 2
Achse | 2
Kamerahalterung | 1
ESC | 4
M3 Schrauben | 27
M3 Beilagscheiben | 27
M3 Muttern | 27
Raspberry Pi Camera | 1
Stirnzahnrad1 | 2
Stirnzahnrad2 | 2
servo_SM-S2309S | 2

### 2.3.2 Autodesk EAGLE

EAGLE ist eine skriptfähige EDA-Anwendung (Electronic Design Automation) mit Schalt-

plan-Erfassung, Leiterplatten-Layout, Auto-Router und CAM-Funktionen (Computer Aided

Manufacturing). EAGLE steht dabei für Easy Applicable Grafischer Layout-Editor.

13

Das Programm bietet eine grafische Benutzeroberfläche und ein Menüsystem mit mehreren

Fenstern für die Bearbeitung, das Projektmanagement und die Anpassung der Schnittstellen-

und Designparameter. Das System kann über Maus, Tastaturkürzel oder durch Eingabe be-

stimmter Befehle in einer eingebetteten Befehlszeile gesteuert werden. Mehrere Wiederho-

lungsbefehle können zu Skriptdateien kombiniert werden. Es ist auch möglich, Entwurfsda-

teien unter Verwendung einer EAGLE-spezifischen objektorientierten Programmiersprache

zu untersuchen.

### 2.3.3 Arduino IDEl

Arduino bringt eine eigene integrierte Entwicklungsumgebung (IDE) mit, die auf Wiring

IDE basiert. Dabei handelt es sich um eine Java-Anwendung, die für die gängigen Plattfor-

men Windows, Linux und MacOS kostenlos verfügbar ist. Sie basiert auf der IDE von Pro-

cessing, einer auf die Einsatzbereiche Grafik, Simulation und Animation spezialisierten Ent-

wicklungsumgebung. Die Arduino-IDE bringt einen Code-Editor mit und bindet gcc als

Compiler ein. Zusätzlich werden die avr-gcc-Library und weitere Arduino-Librarys einge-

bunden, die die Programmierung in C und C++ stark vereinfachen. Arduino kann verwendet

werden, um eigenständige interaktive Objekte zu steuern oder um Softwareanwendungen

auf Computern zu interagieren (z.B. Adobe Flash, Processing, Max/MSP, Pure Data, diverse

Skriptsprachen, etc.)

Für ein funktionstüchtiges Programm genügt es, zwei Funktionen zu definieren:

- setup() – wird beim Start des Programms (entweder nach dem Übertragen auf das

Board oder nach Drücken des Reset-Tasters) einmalig aufgerufen, um z. B. Pins als

Eingang oder Ausgang zu definieren.

- loop() – wird durchgehend immer wieder durchlaufen, solange das Arduino-Board

eingeschaltet ist.

### 2.3.4 Raspbian

Raspbian ist ein kostenloses Betriebssystem, das auf Debian basiert und für die Raspberry

Pi-Hardware optimiert ist. Ein Betriebssystem ist die Menge der grundlegenden Programme

und Dienstprogramme, die den Raspberry Pi laufen lassen. Raspbian bietet jedoch mehr als

14

ein reines Betriebssystem: Es enthält mehr als 35.000 Pakete, vorkompilierte Software in

einem schönen Format für die einfache Installation auf dem Raspberry Pi. Dieses Betriebs-

system basiert auf einem Debian-9-System (Debian Stretch) der ARM-hard-float-

Architektur (armhf) mit Anpassungen an den Befehlssatz für den ARMv6-Prozessor. Als

grafische Oberfläche wird LXDE vorkonfiguriert. Das etwa 3 GB große Image kann auf SD-

Karten mit 4 GB oder mehr übertragen werden. Nach dem Bootvorgang kann die Größe der

Raspbian-Partition auf die gesamte SD-Karte erweitert werden. Die Raspberry Pi Founda-

tion erstellt auf Basis der Raspbian-Distribution ein eigenes Raspbian-Image mit passender

Firmware für die Raspberry-Pi-Modelle, es wird daher empfohlen, die Distribution immer

von der Raspberry Pi Foundation zu beziehen.

### 2.3.5 Python

Das Pi im Namen des Raspberry Pi leitet sich von der Programmiersprache Python ab: Die

Schöpfer des Minicomputers wollten damit zum Ausdruck bringen, dass diese moderne

Skriptsprache besonders zu empfehlen ist.

Python ist eine universelle, üblicherweise interpretierte höhere Programmiersprache. Sie hat

den Anspruch, einen gut lesbaren, knappen Programmierstil zu fördern. So werden beispiels-

weise Blöcke nicht durch geschweifte Klammern, sondern durch Einrückungen strukturiert.

Python unterstützt mehrere Programmierparadigmen, z. B. die objektorientierte, die aspek-

torientierte und die funktionale Programmierung. Ferner bietet es eine dynamische Typisie-

rung. Wie viele dynamische Sprachen wird Python oft als Skriptsprache genutzt.

Die Sprache hat ein offenes, gemeinschaftsbasiertes Entwicklungsmodell, das durch die ge-

meinnützige Python Software Foundation, die de facto die Definition der Sprache in der

Referenzumsetzung CPython pflegt, gestützt wird.

Wegen ihrer klaren und übersichtlichen Syntax gilt Python als einfach zu erlernen. Sie be-

sitzt eine umfangreiche Standardbibliothek und zahlreiche Pakete im Python Package Index.

Zur Standardinstallation von Python gehört eine integrierte Entwicklungsumge- bung na-

mens IDLE.

Raspbian bringt die Python-Entwicklungsumgebung IDLE bereits vorinstalliert auf dem

Desktop mit, sodass bei Bedarf direkt losgelegt werden kann.

IDLE besteht im Wesentlichen aus drei Komponenten:

15

- Die Python-Shell: Beim Starten von IDEL öffnet sich zuerst das Python-Shell-

Fenster. Die Shell ist eine Anwendung, mit der Sie direkt mit dem Python-In- terpre-

ter kommunizieren können: Sie können auf der Kommandozeile einzel- ne Python-

Anweisungen eingeben und ausführen lassen. Ein Python-Programm, das eine Bild-

schirmausgabe liefert, gibt diese in einem Shell-Fenster aus.

- Der Programmeditor: Das ist eine Art Textverarbeitungsprogramm zum Schreiben

von Programmen. Sie starten den Programmeditor vom Shell-Fens- ter aus

(FILE|NEW WINDOW).

- Der Debugger: Er dient dazu, den Lauf eines Programms zu kontrollieren, um logi-

sche Fehler zu finden.

### 2.3.6 Samba

Samba ist ein freies Programmpaket, das es ermöglicht Windows-Funktionen wie die Datei-

und Druckdienste unter anderen Betriebssystemen zu nutzen und die Rolle eines Domain

Controllers anzunehmen. Es implementiert hierfür unter anderem das Server Message

Block/Common Internet File System-Protokoll (SMB/CIFS-Protokoll). Im Projekt wurde

Samba als DC und DNS verwendet, damit man via RDP über WLAN auf den Pi zugreifen

kann, ohne eine statische IP im Pi hinterlegen zu müssen. Der hostname der Drohne lautet

„Mohne“.

16

### BEGINN Systems Engineering – Christian Gruber ###

### 3. SYSTEM LIFE CYCLE

As part of the Mars Explorer project, the insights gained from the courses Systems Engi-

neering, Embedded Systems and Project Management will find application as well as a Fab-

lab environment, mechanical and electronic component production and board production.

### 3.1 System requirements

### 3.1.1 Purpose

The purpose of the project, with the provided components, materials, machines and budget,

is the development of an autonomous vehicle suitable for extra-terrestrial exploration mis-

sions. The suitability is checked on five test tracks. The requirements for the vehicle are as

follows:

- Fall without any destruction from a maximum height of 0,5 m
- Water and dust protected
- Dimensions for the transportation by rocket:
- length < 65 cm
- width < 48 cm
- height < 30 cm
- Weight of the vehicle:
- mRover < 10 kg (Earth)
- mRover < 4,5 kg (Mars)
- Type of movement freely selectable, but autonomous
- Budget: 40 €

### 3.1.2 Goal

The project is to lead to an autonomous hybrid quadcopter, which can overcome the tracks

described under 3.6, by switching between driving and flight mode and detects its surround-

ings using an ultrasonic sensor and camera and reacts accordingly to different situations. At

the heart of the vehicle is a Raspberry Pi and an Arduino, which receive data, process data

and forward data.

17

Sub goals for the project are:

- Design and manufacture of the chassis
- Construct and manufacture the rotating mechanism of the rear wings to switch be-

tween driving and flying modes

- Design and manufacture circuit board
- Programming the motor control incl. ESC calibration to create the conditions for

flying

- Realize autonomous mode with the help of sensors (programming for ultrasonic sen-

sor and camera)

- Control code and PID control to keep the quadcopter stable in the air

### 3.1.3 Limitations

Switching on and off takes place in manual mode, while flying and driving, the "Mohne"

acts autonomously. The distance to the ground is not measured. Obstacles are overcome by

switching from the driving mode to the flying mode and then returning to the driving mode.

The system only must work in good weather conditions and on given courses, which is why

only one straight-ahead flight is realized.

### 3.2 Design alternatives

In order to decide on a design for this project, certain limiting factors had to be taken into

account, namely the maximum size and maximum permissible weight that the vehicle may

have in order to be able to be transported from the launcher to Mars. Even under the condi-

tion that the electronic components, which must be enclosed and fastened somewhere inside

the fuselage, must be protected from dust and water, the possibilities were further narrowed.

The given budget and time limit as well as the available materials and machines limited

further possibilities. After some deliberations and research on how to overcome the individ-

ual hurdles of the test tracks, it was decided that a hybrid quadcopter would be developed.

Also due to the fact that drones are becoming increasingly popular and are being used in

more and more areas of application, we wanted to meet this challenge and renounce the

construction of a conventional Mars rover.

18
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

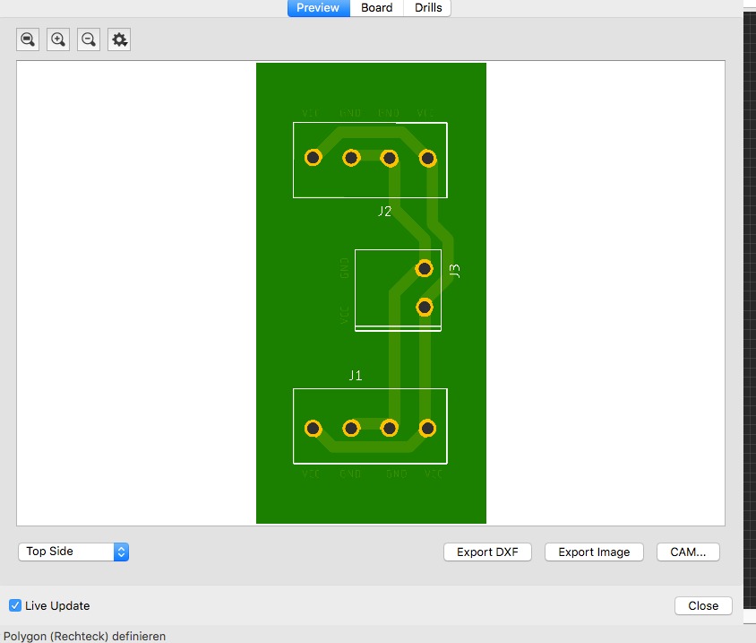
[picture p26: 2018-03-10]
01_Projektmanagement/Bilder/PCB_simulated.jpeg

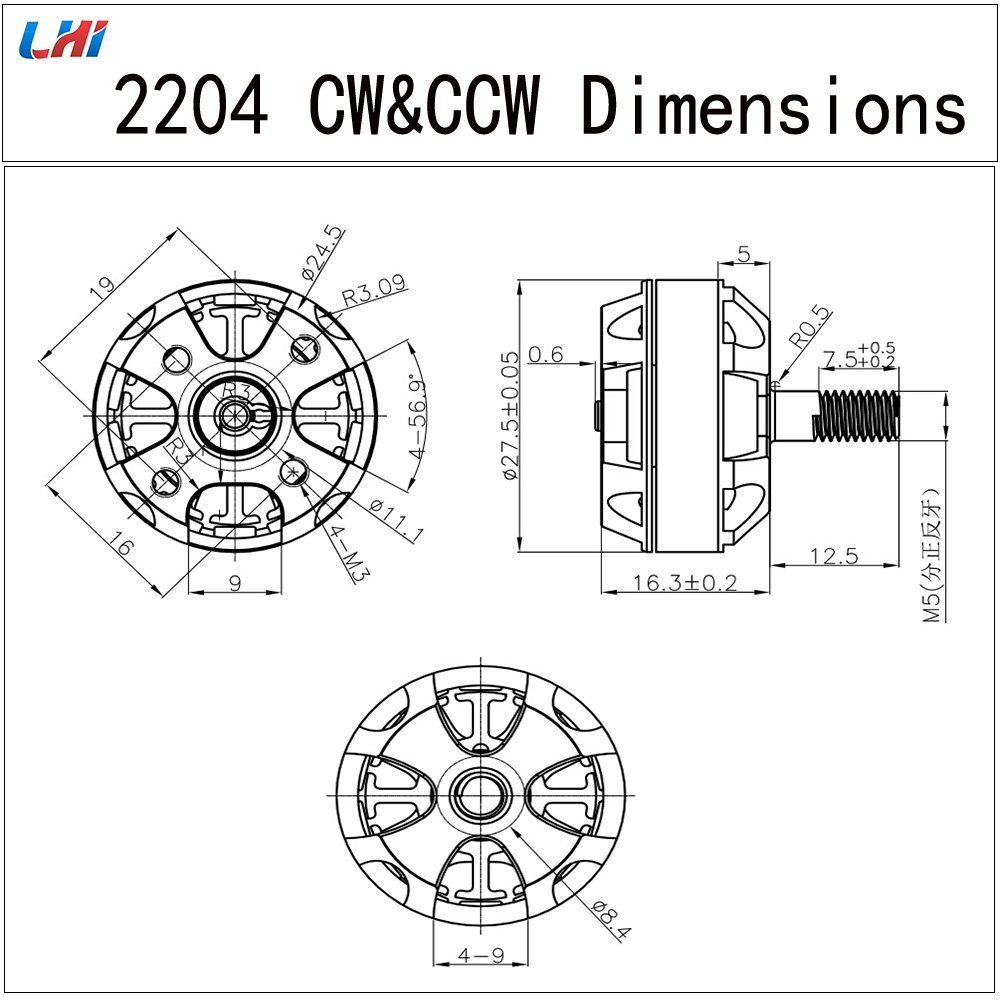
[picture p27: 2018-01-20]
03_Konstruktion/Motor_Technische_Zeichnung.jpg

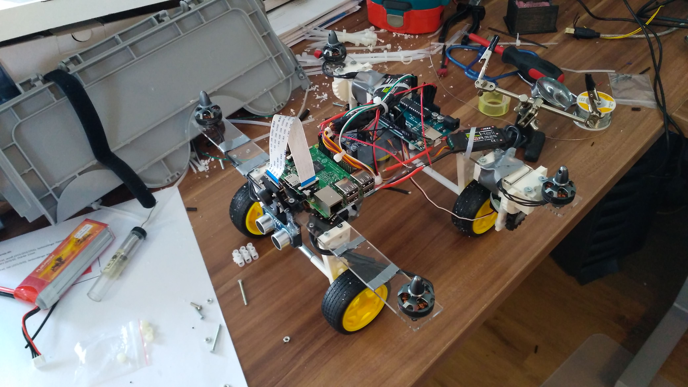
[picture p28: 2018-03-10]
01_Projektmanagement/Bilder/IMG-20180209-WA0003.jpeg

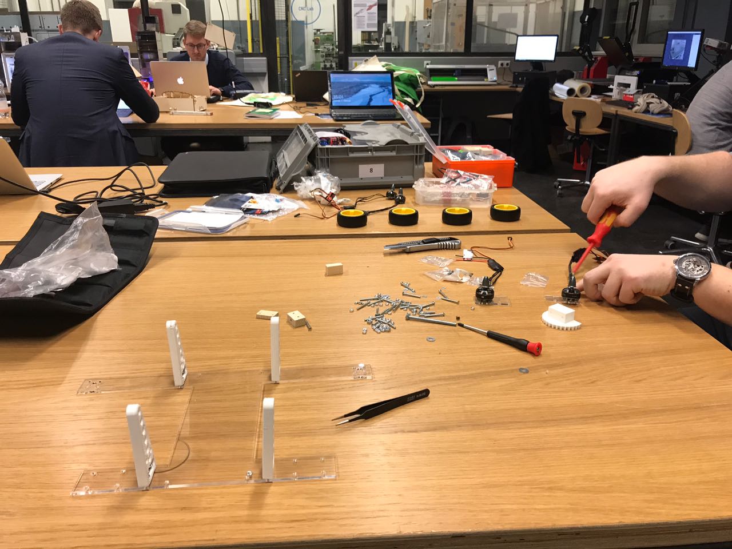
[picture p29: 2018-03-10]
01_Projektmanagement/Bilder/IMG-20180202-WA0005.jpg

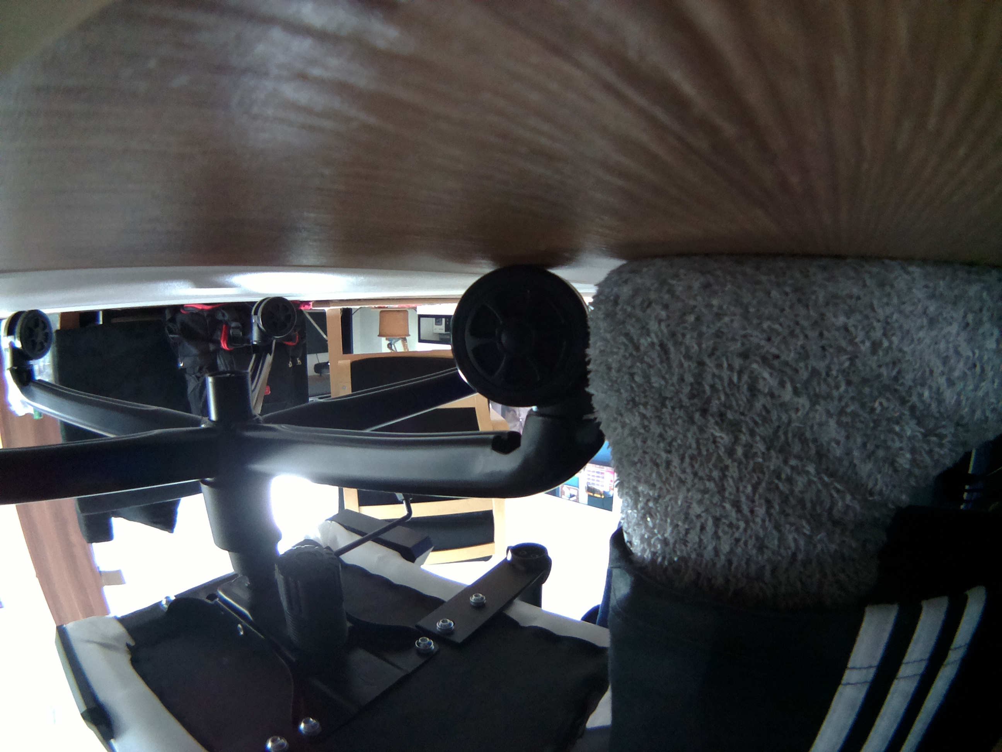
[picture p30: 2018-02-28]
02_Quellcode/Pi Programme/output.jpg

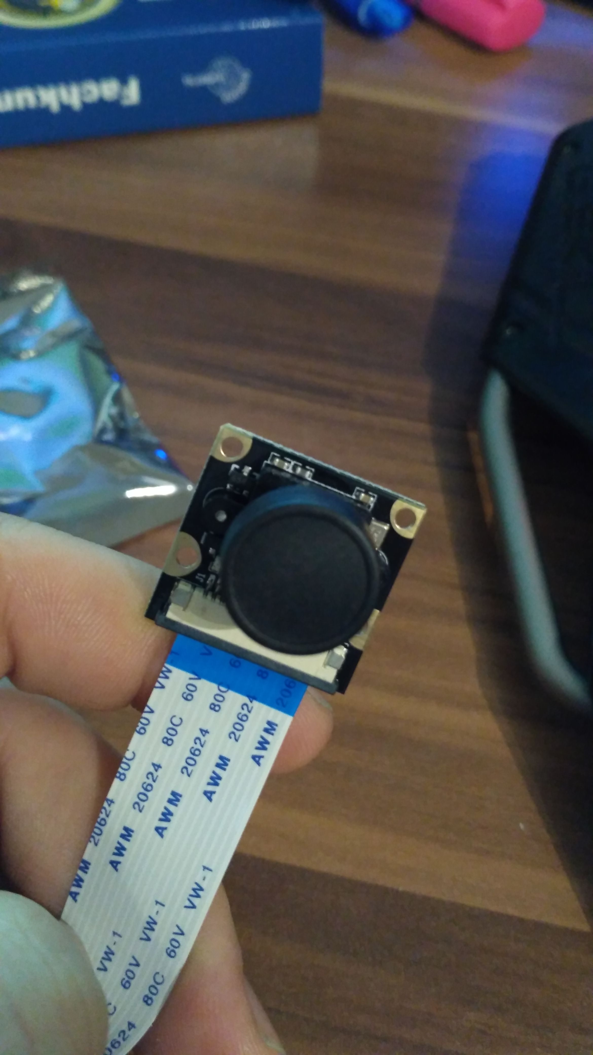
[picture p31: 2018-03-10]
01_Projektmanagement/Bilder/IMG-20180130-WA0003.jpeg

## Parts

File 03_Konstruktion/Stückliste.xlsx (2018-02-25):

Name | Anzahl | Anmerkungen
Chassis mit motorlöcher | 1
Platzhalter Zylinder Klein | 4
Metall Stab M5 | 1
Chassis-2 | 1
Kegelrad | 1
EMax Motor | 4 | STEP AP203
RaspberryPi2 STEP214 | 1 | STEP AP214
Metall Stab M5_MIR | 1
StirnradUNDServo_MIR | 1
Propeller | 4
arduino uno | 1 | SolidWorks IGES file using analytic representation for surfaces
MPU 6050 IMU | 1
Abstandhalter_MPU | 1
LiPo Akku | 1
PDB | 4 | SolidWorks IGES file using analytic representation for surfaces
Ultrasonic Sensor Halterung | 1
USS | 1 | STEP AP214
Wheel ALL | 2
Radaufhängung | 4
Wheel ALL1_MIR | 2
Achse | 2
Kamerahalterung | 1
ESC | 4
M3 Schrauben | 27
M3 Beilagscheiben | 27
M3 Muttern | 27
Raspberry Pi Camera | 1
Stirnzahnrad1 | 2
Stirnzahnrad2 | 2
servo_SM-S2309S | 2

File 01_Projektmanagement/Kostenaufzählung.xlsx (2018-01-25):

Budget Kalkulation
Material | Kosten
Ladegerät und Akku | 0€ (geliehen)
LHI 2CW 2CCW MT2204Ⅱ 2300KV Brushless Motor | 16.99 €
Carbon propeller | 5.60 €
4X MR.RC 12A Speed Controller ESC | 12.92 €
MPU 6050 | 5.99 €
Kleinteile(Kabelbinder, Tape, Aluachsen) | 5 €
Summe | 46.50 €

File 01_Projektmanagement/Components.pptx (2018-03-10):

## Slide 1

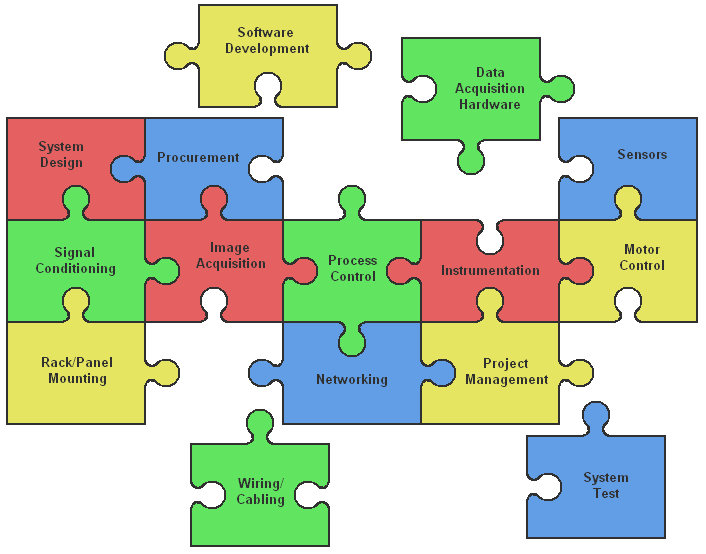
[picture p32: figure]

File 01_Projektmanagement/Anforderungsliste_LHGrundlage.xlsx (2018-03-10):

Anforderungsliste des Projekts |  | Sharepointumgebung Produkt- und Innovationsmanagement
 | Stand | 2018-03-10
Id | Titel | Beschreibung | Kategorie | Priorität | Abgestimmt | Reviewkommentar | Aufwandschätzung in PT | Quelle | Subsystem
1 | Sturz aus 50cm | Muss ohne Schäden überstanden werden | Randbedingung | Pflicht
2 | Sandfahren gerade aus |  | Randbedingung | Pflicht
3 | Stufen überwinden 10-60cm |  | Randbedingung
4 | Wasser und Sand überstehen gerade aus | Drohne muss wasserdicht sein | Randbedingung
5 | Hindernisse umfahren 40x40 rot |  | Randbedingung
6 | Beastmode = Alles schaffen |  | Randbedingung
7 | Drohen (Mohne) fertigen
8 | autonom fliegen
9 | Fahrmodus | Drohne muss die meiste zeit fahren
10 | Hindernisserkennung + Zielanflug | Mit Kamera und Ultraschallsensor
11 | Notstop | im notfall dünnes seil, anglerschnurr

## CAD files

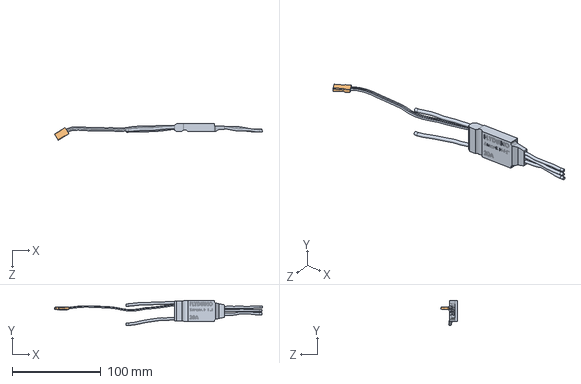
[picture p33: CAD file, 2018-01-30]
03_Konstruktion/28-2-2013-100 - ESC Flyduino SimonK 20A.SLDASM
234.5 x 28.3 x 18.7 mm
28-2-2013-001 - ESC Flyduino SimonK 20A body
28-2-2013-002 - ESC 3-pin connector

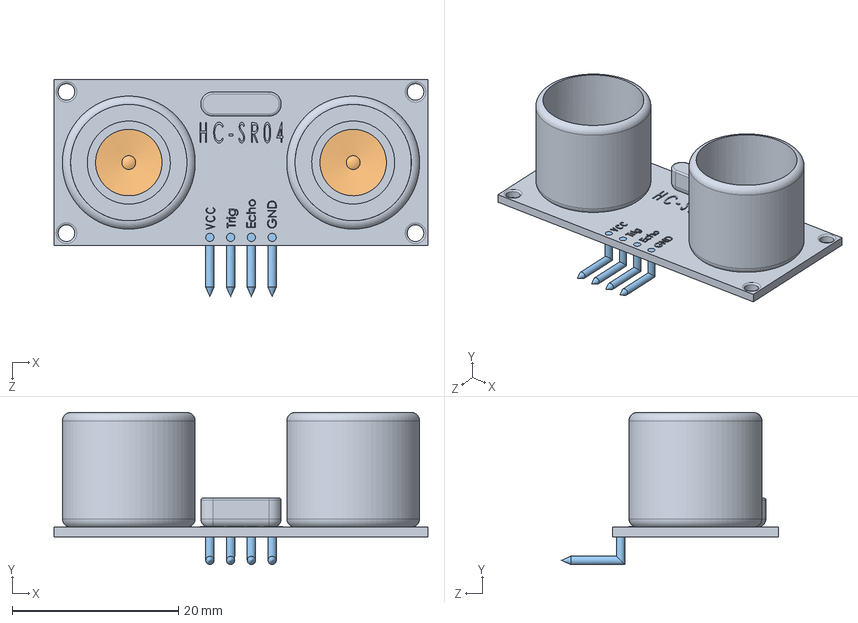
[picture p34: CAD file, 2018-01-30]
03_Konstruktion/Assem3.SLDASM
45.0 x 18.3 x 26.1 mm
UltraSonic
pin header x 4

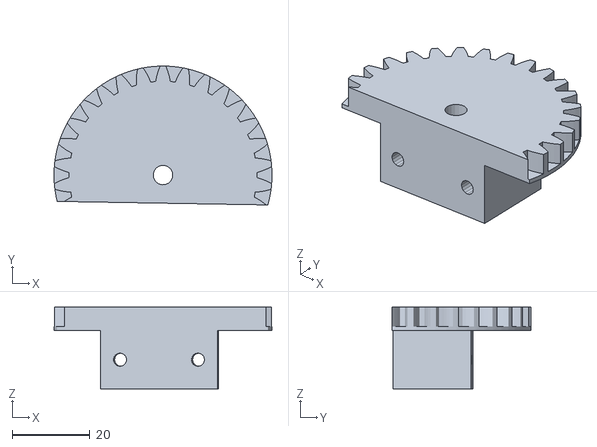
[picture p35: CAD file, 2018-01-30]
03_Konstruktion/Exporte/Stirnzahnrad11_MIR_2.stl
55.9 x 35.6 x 21.0

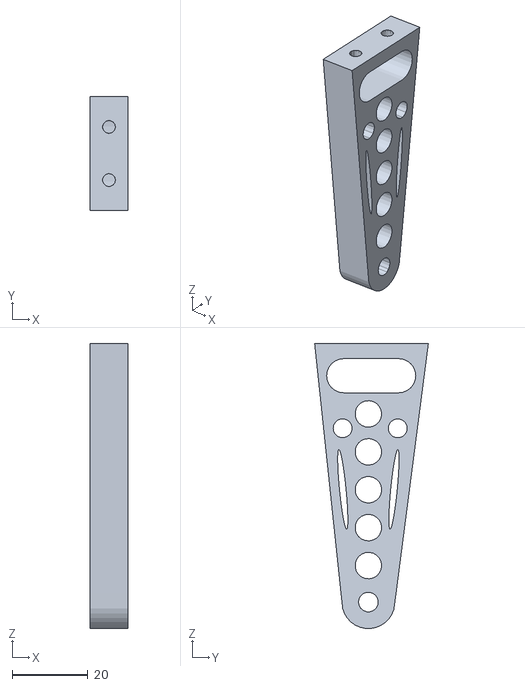
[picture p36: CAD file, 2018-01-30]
03_Konstruktion/Exporte/Radaufhängung.stl
10.0 x 30.0 x 75.2

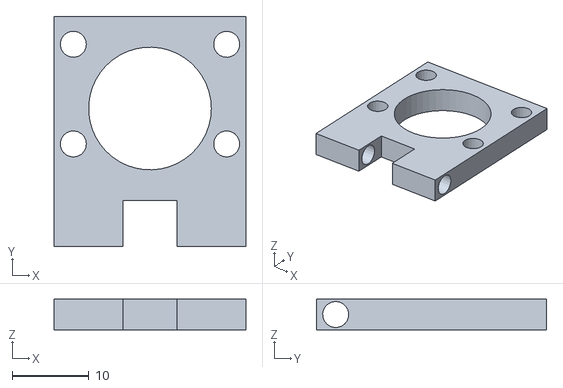
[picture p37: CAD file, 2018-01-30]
03_Konstruktion/Exporte/kamera ot.stl
25.0 x 30.0 x 4.00

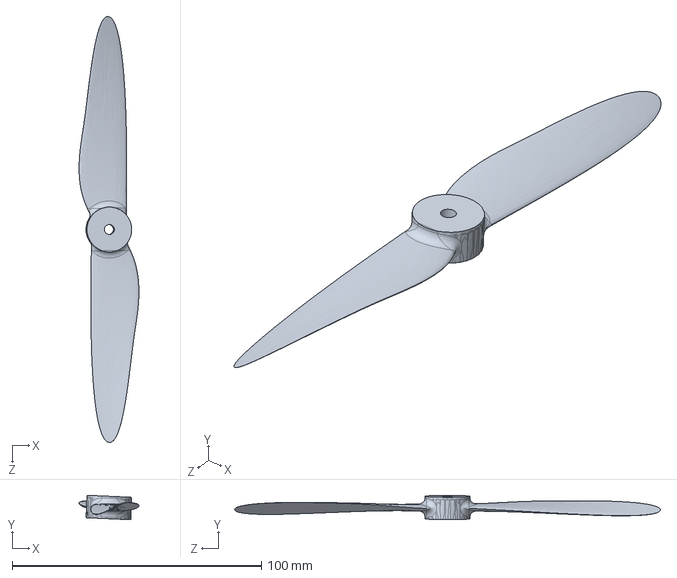
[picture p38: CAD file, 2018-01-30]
03_Konstruktion/propeller1.SLDPRT
24.0 x 9.79 x 170.8 mm

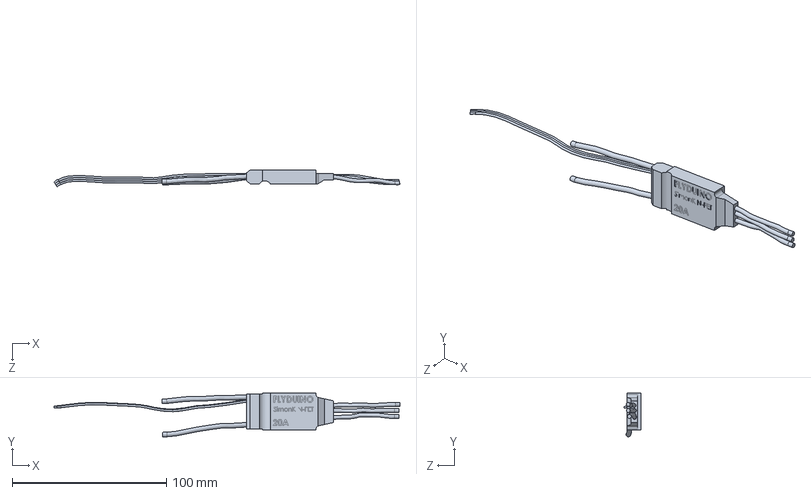
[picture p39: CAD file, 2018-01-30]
03_Konstruktion/28-2-2013-001 - ESC Flyduino SimonK 20A body.SLDPRT
224.0 x 28.3 x 11.1 mm

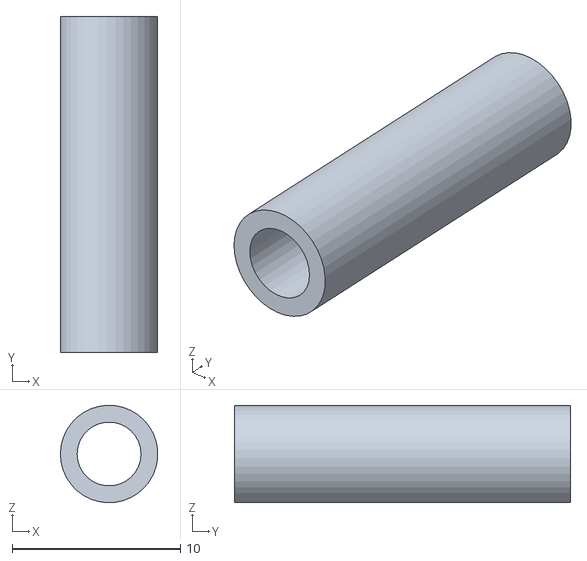
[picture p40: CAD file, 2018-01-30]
03_Konstruktion/Exporte/Platzhalter Zylinder Klein2.stl
5.79 x 20.0 x 5.79

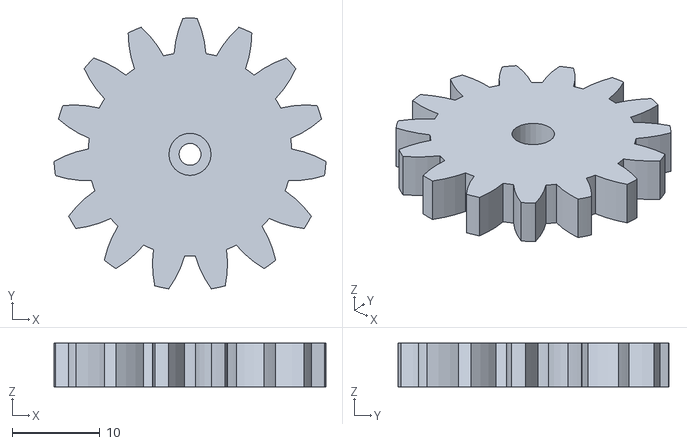
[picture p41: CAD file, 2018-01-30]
03_Konstruktion/Exporte/Stirnzahnrad21_MIR_2.stl
31.0 x 30.8 x 5.00

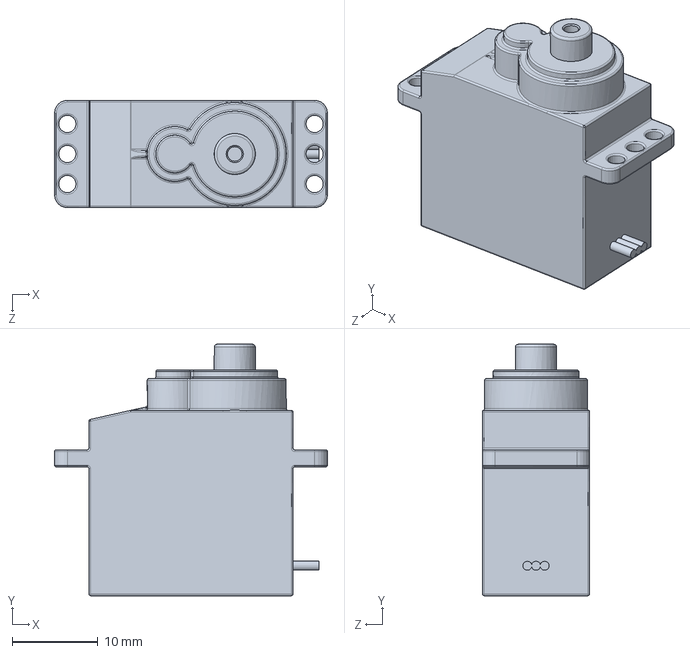
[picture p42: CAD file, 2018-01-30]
03_Konstruktion/servo_SM-S2309S.SLDPRT
31.8 x 29.3 x 12.5 mm

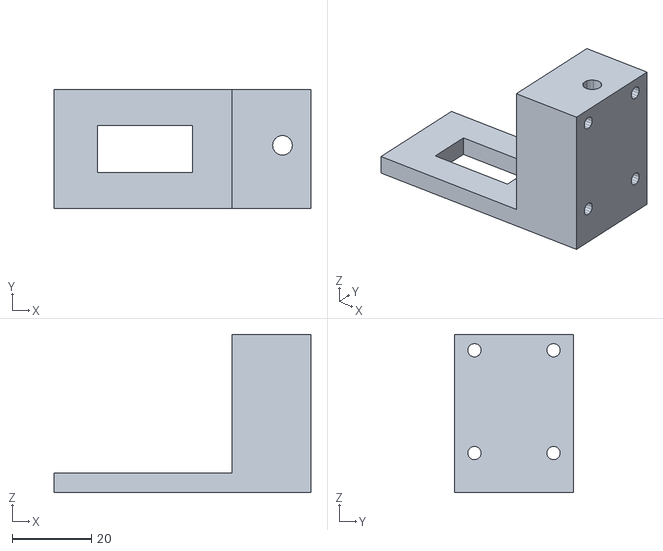
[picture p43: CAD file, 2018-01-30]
03_Konstruktion/Exporte/L-Halterung Servo_MIR1_2.stl
65.0 x 30.0 x 40.0

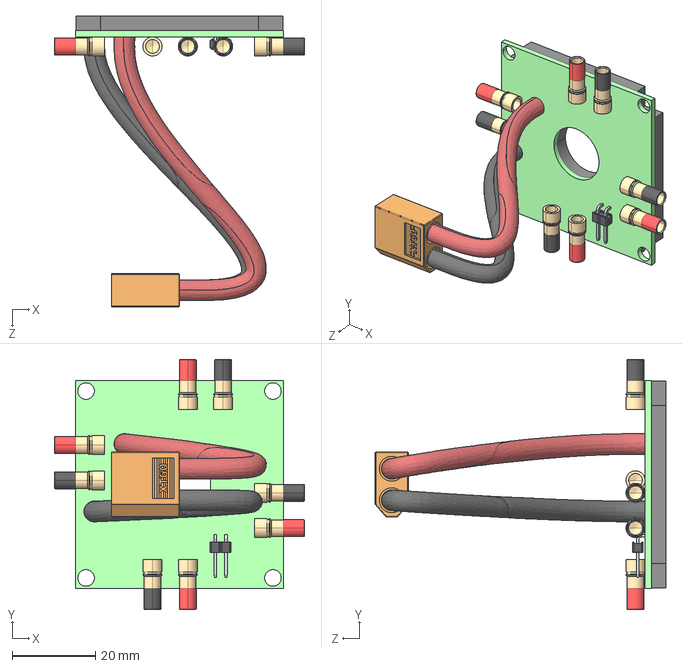
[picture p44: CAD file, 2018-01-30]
03_Konstruktion/3D VIEW - Planche de distribution de puissance 4x20A.IGS
60.2 x 60.2 x 70.0 mm

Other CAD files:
03_Konstruktion/Chassis_zweiteEbene.dwg
03_Konstruktion/USS.STEP
03_Konstruktion/chassis mit motorlöcher.dwg
03_Konstruktion/01000A-010-001-PN.ipt
03_Konstruktion/01000A-040-001-SC.ipt
03_Konstruktion/01000A-040-001-UE.ipt
03_Konstruktion/01000A-040-002-LE.ipt
03_Konstruktion/01000A-040-005-MR.ipt
03_Konstruktion/01000A-040-006-RW.ipt
03_Konstruktion/01000A-040-007-CM.ipt
03_Konstruktion/01000A-050-001-BH.ipt
03_Konstruktion/01000A-050-002-BC.ipt
03_Konstruktion/01000A-050-004-SW.ipt
03_Konstruktion/01000A-050-Motor Bearing.iam
03_Konstruktion/28-2-2013-002 - ESC 3-pin connector.SLDPRT
03_Konstruktion/2xAAA_ass.STEP
03_Konstruktion/2xAAA_ass.ipt
03_Konstruktion/3D VIEW - Planche de distribution de puissance 4x20A.ipt
03_Konstruktion/Abstandhalter_MPU.ipt
03_Konstruktion/Achse.ipt
03_Konstruktion/Achsenhalterung.ipt
03_Konstruktion/Assem3.ipt
03_Konstruktion/Audio.ipt
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

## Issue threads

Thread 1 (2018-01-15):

Beispiele Lesen - ToDo für jeden! ;-)

gchrizZz, 2018-01-15:
http://www.instructables.com/id/The-Drone-Pi/

http://www.instructables.com/id/Autonomous-Cardboard-Rasberry-Pi-Controlled-Quad/

https://www.amazon.de/Air-Hogs-6037213-Hyper-Stunt-Drone/dp/B01N11JWTK

Unser Modell soll eine Mischung aus dem Spielzeug von Amazon und den Qudrocoptern werden. (Mit 4 Räder statt 2)

gchrizZz, 2018-01-19:
http://www.rc-network.de/magazin/artikel_02/art_02-0037/Standschub.pdf

Hilfreich zur Berechnung und Argumentation fliegt auf dem Mars.

MaxMoebes, 2018-02-03:
Erledigt.

Closed 2018-02-03.

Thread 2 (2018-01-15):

Radaufhängung und Achsen konstruieren

gchrizZz, 2018-01-15:
Radaufhängung für die vorhandenen Räder konstruieren (wir müssen sparen):
3D Druckteil welches wir evtl. an das Chassis schrauben.
Achse warscheinlich aus Alu.

Nachfolgendes nicht mehr gültig!!!:
_https://www.amazon.de/Air-Hogs-6037213-Hyper-Stunt-Drone/dp/B01N11JWTK

Zusätzlich zur Konstruktion Fertigungsmöglichkeiten neben 3D-Druck erarbeiten.

Auch 3D kann stabil sein:
https://www.youtube.com/watch?v=vjvlB7RjnYI
https://www.youtube.com/watch?v=K6wfctAFrvw_

MaxMoebes, 2018-02-03:
Konstruktion / CAD-Modell mit Inventor erstellt.

Closed 2018-02-03.

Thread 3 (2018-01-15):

Chassi konstruieren

gchrizZz, 2018-01-15:
Möglichst einfach zu fertigendes und leichtes Chassi konstruieren.
Elektronik muss jedoch vor Wassser geschützt sein.

Max Maße Gesamtfahrzeug:
Länge < 65 cm
Breite < 48 cm
Höhe < 30cm
<10kg

gchrizZz, 2018-01-19:
https://www.thingiverse.com/thing:1694036
As simple as possible

MaxMoebes, 2018-02-03:
Konstruktion / CAD-Modell mit Inventor erstellt.

Closed 2018-02-03.

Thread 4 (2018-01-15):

Steuerungscode programmieren

gchrizZz, 2018-01-15:
Code für rasberry Pi programmieren.
Programmiersprache egal.

Code muss:
4 Motoren steuern können
Gyroskop auslesen können und dementsprechend steuern
Objekterkennung mit der Kamera
Evtl. Ultraschallsensoren auslesen
Notstop via SSH über WLAN o.ä. einbauen

gchrizZz, 2018-01-16:
https://github.com/PiStuffing/Quadcopter ... wow...

gchrizZz, 2018-01-16:
https://github.com/matthew-t-watson/Picopter ..dito...

LudiP, 2018-01-20:
http://www.electronoobs.com/eng_robotica_tut6.php
sehr cooler arduino code mit anleitung und erklärung

MaxMoebes, 2018-02-03:
Programmieren ist doof

LudiP, 2018-02-05:
https://copterflieger.com/2015/01/26/arduino-multiwii-software/

Erklärung um die Multiwii Software auf den Arduino zu spielen

MaxMoebes, 2018-02-09:
Hier der Link vom Chris für die i2C Verbindung, sollten wir dann am 09.02.17 schaffen einzurichten
https://oscarliang.com/raspberry-pi-arduino-connected-i2c/

LudiP, 2018-02-09:
https://github.com/lobodol/drone
pid dingens

Closed 2018-03-10.

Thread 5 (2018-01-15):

Bestellungen in das Forum in moodle eintragen

gchrizZz, 2018-01-15:
https://weblearn.fh-kufstein.ac.at/mod/forum/view.php?id=12233

Motoren
Akku
Rotorblätter
Welle (Alu) + Schraube + Beilagscheibe evtl. nicht nötig sofern Teller gefräst wird aber viel Materialverbrauch
Schrauben Muttern und Beilagscheiben
Mosgummi
Plastiktüte/Folie
Panzertape!!!
Kabelbinder

gchrizZz, 2018-01-29:
Nicht mehr nötig

MaxMoebes, 2018-02-03:
Bestellungen sind bereits erfolgt.

Closed 2018-02-03.

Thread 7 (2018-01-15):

Platinenlayout konstruieren

gchrizZz, 2018-01-15:
Konstruktion mit Eagle

MaxMoebes, 2018-02-03:
Platine ist fertig und getestet, funktioniert

MaxMoebes, 2018-02-03:
[Mohne Platine.zip](https://github.com/gchrizZz/RTW/files/1691622/Mohne.Platine.zip)

MaxMoebes, 2018-02-03:
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

Closed 2018-02-03.

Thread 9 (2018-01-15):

Chassis fertigen

gchrizZz, 2018-01-15:

MaxMoebes, 2018-02-03:
Chassis mittels Lasercutter (Plexiglas) ausgeschnitten. Einzelne teile mit 3D-Druck gefertigt.

Closed 2018-02-03.

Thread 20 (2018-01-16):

Gesamt-Elektronik konzeptionieren

gchrizZz, 2018-01-16:
Elektronik ist aufwendiger als gedacht...
Und wir brauceh viele Bauteile:

https://www.amazon.de/LHI-MT2204%E2%85%A1-Brushless-Quadcopter-Multicopter/dp/B01E3OT7NE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

https://www.amazon.de/GDD2018-BLHeli-12A-Regler-Quadcopter-Acromodelle/dp/B01D01HVI4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

https://www.amazon.de/3-Achsen-Gyroskop-3-Achsen-Accelerometer-Beschleunigungssensor-Neigungssensor-Raspberry/dp/B01F11WXN4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

https://www.amazon.de/GoolRC-Hochleistungs-Luftschrauber-Multirotor-Quadcopter/dp/B00VE7RNQM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

https://www.amazon.de/dp/B01MZHNFDQ/ref=sspa_dk_detail_6?psc=1 + Ladegerät evtl..

ChristophJungwirth, 2018-01-19:
https://www.ebay.de/itm/Emax-simon-series-ESC-Speed-Controller-Regler-6A-12A-20A-25A-30A-40A-BEC-/232196500670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

gchrizZz, 2018-01-19:
Power distributionboard, welches wir selber bauen können.
https://hobbyking.com/en_us/hobby-king-quadcopter-power-distribution-board.html

LudiP, 2018-01-20:
https://www.raspberrypi.org/documentation/usage/gpio-plus-and-raspi2/

die Pinbelegung fürn Pi

MaxMoebes, 2018-02-03:
Alle Teile Bestellt und geliefert. Power Distribution Board wurde selbst gefertigt. Siehe Platinenkonstruktion.

Closed 2018-02-03.

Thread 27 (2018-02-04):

Simonk ESC calibrieren und motorsterung programmieren

gchrizZz, 2018-02-04:

gchrizZz, 2018-02-04:
Es gibt zwei möglichkeiten: Analog oder PWM beides mit Arduino und 4 ESCs möglich
http://www.instructables.com/id/ESC-Programming-on-Arduino-Hobbyking-ESC/
https://github.com/nickshek/arduino-simonK-esc-calibration
http://www.techmonkeybusiness.com/esc-calibration-using-an-arduino.html

MaxMoebes, 2018-02-08:
Anbei der Code um 1-4 ESC (+Motoren, je nach Bedarf) anzusteuern. Kalibrierung damit wahrscheinlich nicht möglich.
[Kalibrierung_ESC_hobbyking_1_bis_4_Motoren.ino.zip](https://github.com/gchrizZz/RTW/files/1705424/Kalibrierung_ESC_hobbyking_1_bis_4_Motoren.ino.zip)

Closed 2018-03-08.

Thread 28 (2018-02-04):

Steckverbindung HV Akku und Stromplatine fertigen

gchrizZz, 2018-02-04:

MaxMoebes, 2018-02-08:
- Passender Stecker für Akku gekauft (5€, siehe Rechnung)
- Power Distribution Board (selbst gefertigt) hat wegen zu hoher Belastung versagt.
   (Ersatzboard bestellt)

Closed 2018-03-08.

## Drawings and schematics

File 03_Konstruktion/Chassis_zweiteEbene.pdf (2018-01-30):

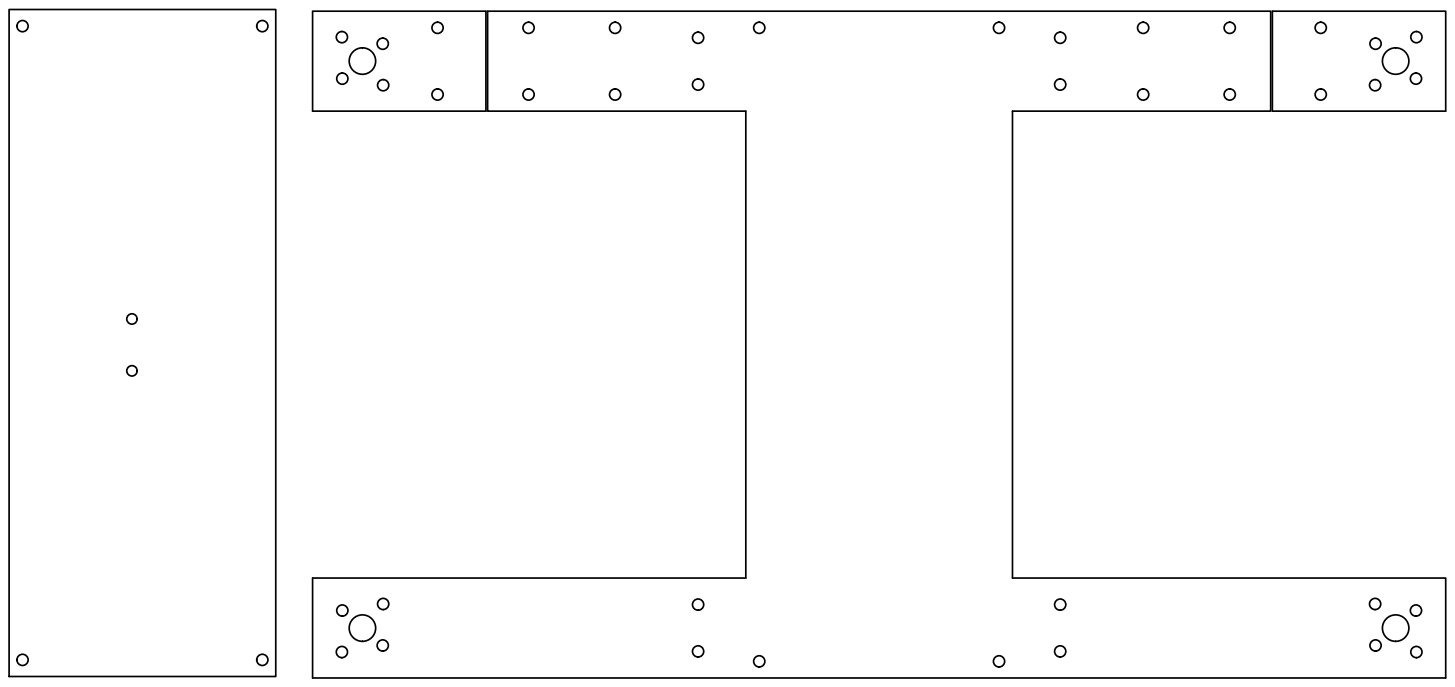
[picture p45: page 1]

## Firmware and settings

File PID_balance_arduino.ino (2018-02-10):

#include <Wire.h>
#include <Servo.h>


Servo right_prop;
Servo right2_prop;
Servo left2_prop;
Servo left_prop;

/*MPU-6050 gives you 16 bits data so you have to create some 16int constants
 * to store the data for accelerations and gyro*/

int16_t Acc_rawX, Acc_rawY, Acc_rawZ,Gyr_rawX, Gyr_rawY, Gyr_rawZ;
 

float Acceleration_angle[2];
float Gyro_angle[2];
float Total_angle[2];




float elapsedTime, time, timePrev;
int i;
float rad_to_deg = 180/3.141592654;

float PID, pwmLeft, pwmRight, error, previous_error;
float pid_p=0;
float pid_i=0;
float pid_d=0;
/////////////////PID CONSTANTS/////////////////
double kp=3.55;//3.55
double ki=0.005;//0.003
double kd=2.05;//2.05
///////////////////////////////////////////////

double throttle=1300; //initial value of throttle to the motors
float desired_angle = 0; //This is the angle in which we whant the
                         //balance to stay steady


void setup() {
  Wire.begin(); //begin the wire comunication
  Wire.beginTransmission(0x68);
  Wire.write(0x6B);
  Wire.write(0);
  Wire.endTransmission(true);
  Serial.begin(250000);
  right_prop.attach(6); //attatch the right motor to pin 3      hinten rechts 11 vorne rechts 6
  left_prop.attach(5);  //attatch the left motor to pin 5     hinten links 10 vorne links 5
  right2_prop.attach(11);
  left2_prop.attach(10);


  
  time = millis(); //Start counting time in milliseconds
  /*In order to start up the ESCs we have to send a min value
   * of PWM to them before connecting the battery. Otherwise
   * the ESCs won't start up or enter in the configure mode.
   * The min value is 1000us and max is 2000us, REMEMBER!*/
  left_prop.writeMicroseconds(1000); 
  right_prop.writeMicroseconds(1000);
  left2_prop.writeMicroseconds(1000);
  right2_prop.writeMicroseconds(1000);
  delay(7000); /*Give some delay, 7s, to have time to connect
                *the propellers and let everything start up*/ 
}//end of setup void

void loop() {

/////////////////////////////I M U/////////////////////////////////////
    timePrev = time;  // the previous time is stored before the actual time read
    time = millis();  // actual time read
    elapsedTime = (time - timePrev) / 1000; 
  
  /*The tiemStep is the time that elapsed since the previous loop. 
   * This is the value that we will use in the formulas as "elapsedTime" 
   * in seconds. We work in ms so we haveto divide the value by 1000 
   to obtain seconds*/

  /*Reed the values that the accelerometre gives.
   * We know that the slave adress for this IMU is 0x68 in
   * hexadecimal. For that in the RequestFrom and the 
   * begin functions we have to put this value.*/
   
     Wire.beginTransmission(0x68);
     Wire.write(0x3B); //Ask for the 0x3B register- correspond to AcX
     Wire.endTransmission(false);
     Wire.requestFrom(0x68,6,true); 
   
   /*We have asked for the 0x3B register. The IMU will send a brust of register.
    * The amount of register to read is specify in the requestFrom function.
    * In this case we request 6 registers. Each value of acceleration is made out of
    * two 8bits registers, low values and high values. For that we request the 6 of them  
    * and just make then sum of each pair. For that we shift to the left the high values 
    * register (<<) and make an or (|) operation to add the low values.*/
    
     Acc_rawX=Wire.read()<<8|Wire.read(); //each value needs two registres
     Acc_rawY=Wire.read()<<8|Wire.read();
     Acc_rawZ=Wire.read()<<8|Wire.read();

 
    /*///This is the part where you need to calculate the angles using Euler equations///*/
    
    /* - Now, to obtain the values of acceleration in "g" units we first have to divide the raw   
     * values that we have just read by 16384.0 because that is the value that the MPU6050 
     * datasheet gives us.*/
    /* - Next we have to calculate the radian to degree value by dividing 180º by the PI number
    * which is 3.141592654 and store this value in the rad_to_deg variable. In order to not have
    * to calculate this value in each loop we have done that just once before the setup void.
    */

    /* Now we can apply the Euler formula. The atan will calculate the arctangent. The
     *  pow(a,b) will elevate the a value to the b power. And finnaly sqrt function
     *  will calculate the rooth square.*/
     /*---X---*/
     Acceleration_angle[0] = atan((Acc_rawY/16384.0)/sqrt(pow((Acc_rawX/16384.0),2) + pow((Acc_rawZ/16384.0),2)))*rad_to_deg;
     /*---Y---*/
     Acceleration_angle[1] = atan(-1*(Acc_rawX/16384.0)/sqrt(pow((Acc_rawY/16384.0),2) + pow((Acc_rawZ/16384.0),2)))*rad_to_deg;
 
   /*Now we read the Gyro data in the same way as the Acc data. The adress for the
    * gyro data starts at 0x43. We can see this adresses if we look at the register map
    * of the MPU6050. In this case we request just 4 values. W don¡t want the gyro for 
    * the Z axis (YAW).*/
    
   Wire.beginTransmission(0x68);
   Wire.write(0x43); //Gyro data first adress
   Wire.endTransmission(false);
   Wire.requestFrom(0x68,4,true); //Just 4 registers
   
   Gyr_rawX=Wire.read()<<8|Wire.read(); //Once again we shif and sum
   Gyr_rawY=Wire.read()<<8|Wire.read();
 
   /*Now in order to obtain the gyro data in degrees/seconda we have to divide first
   the raw value by 131 because that's the value that the datasheet gives us*/

   /*---X---*/
   Gyro_angle[0] = Gyr_rawX/131.0; 
   /*---Y---*/
   Gyro_angle[1] = Gyr_rawY/131.0;

   /*Now in order to obtain degrees we have to multiply the degree/seconds
   *value by the elapsedTime.*/
   /*Finnaly we can apply the final filter where we add the acceleration
   *part that afects the angles and ofcourse multiply by 0.98 */

   /*---X axis angle---*/
   Total_angle[0] = 0.98 *(Total_angle[0] + Gyro_angle[0]*elapsedTime) + 0.02*Acceleration_angle[0];
   /*---Y axis angle---*/
   Total_angle[1] = 0.98 *(Total_angle[1] + Gyro_angle[1]*elapsedTime) + 0.02*Acceleration_angle[1];
   
   /*Now we have our angles in degree and values from -10º0 to 100º aprox*/
    //Serial.println(Total_angle[1]);

   
  
/*///////////////////////////P I D///////////////////////////////////*/
/*Remember that for the balance we will use just one axis. I've choose the x angle
to implement the PID with. That means that the x axis of the IMU has to be paralel to
the balance*/

/*First calculate the error between the desired angle and 
*the real measured angle*/
error = Total_angle[1] - desired_angle;
    
/*Next the proportional value of the PID is just a proportional constant
*multiplied by the error*/

pid_p = kp*error;

/*The integral part should only act if we are close to the
desired position but we want to fine tune the error. That's
why I've made a if operation for an error between -2 and 2 degree.
To integrate we just sum the previous integral value with the
error multiplied by  the integral constant. This will integrate (increase)
the value each loop till we reach the 0 point*/
if(-3 <error <3)
{
  pid_i = pid_i+(ki*error);  
}

/*The last part is the derivate. The derivate acts upon the speed of the error.
As we know the speed is the amount of error that produced in a certain amount of
time divided by that time. For taht we will use a variable called previous_error.
We substract that value from the actual error and divide all by the elapsed time. 
Finnaly we multiply the result by the derivate constant*/

pid_d = kd*((error - previous_error)/elapsedTime);

/*The final PID values is the sum of each of this 3 parts*/
PID = pid_p + pid_i + pid_d;

/*We know taht the min value of PWM signal is 1000us and the max is 2000. So that
tells us that the PID value can/s oscilate more than -1000 and 1000 because when we
have a value of 2000us the maximum value taht we could sybstract is 1000 and when
we have a value of 1000us for the PWM sihnal, the maximum value that we could add is 1000
to reach the maximum 2000us*/
if(PID < -1000)
{
  PID=-1000;
}
if(PID > 1000)
{
  PID=1000;
}

/*Finnaly we calculate the PWM width. We sum the desired throttle and the PID value*/
pwmLeft = throttle + PID;
pwmRight = throttle - PID;


/*Once again we map the PWM values to be sure that we won't pass the min
and max values. Yes, we've already maped the PID values. But for example, for 
throttle value of 1300, if we sum the max PID value we would have 2300us and
that will mess up the ESC.*/
//Right
if(pwmRight < 1000)
{
  pwmRight= 1000;
}
if(pwmRight > 2000)
{
  pwmRight=2000;
}
//Left
if(pwmLeft < 1000)
{
  pwmLeft= 1000;
}
if(pwmLeft > 2000)
{
  pwmLeft=2000;
}

/*Finnaly using the servo function we create the PWM pulses with the calculated
width for each pulse*/
left_prop.writeMicroseconds(pwmLeft);
left2_prop.writeMicroseconds(pwmLeft);
right2_prop.writeMicroseconds(pwmRight);
right_prop.writeMicroseconds(pwmRight);
previous_error = error; //Remember to store the previous error.

}//end of loop void

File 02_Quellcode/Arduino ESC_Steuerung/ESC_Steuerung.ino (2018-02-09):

#include <Servo.h> 
 
//Create the 4 esc objects
Servo esc1;
Servo esc2;
Servo esc3;
Servo esc4;
 
//Esc pins
int escPin1 = 5;
int escPin2 = 6;
int escPin3 = 10;
int escPin4 = 11;

//Min and max pulse
int minPulseRate        = 1000;
int maxPulseRate        = 2000;
int throttleChangeDelay = 50;
 
//SETUP
void setup() {
  Serial.begin(9600);
  Serial.setTimeout(500);
  
  //Init escs
  initEscs();
}
 
//LOOP
void loop() {
  // Wait for some input
  if (Serial.available() > 0) {
    
    // Read the new throttle value
    int throttle = normalizeThrottle(Serial.parseInt());
    
    // Print it out
    Serial.print("Setting throttle to: ");
    Serial.println(throttle);
    
    // Change throttle to the new value
    changeThrottle(throttle);
  }
 
}
 
//Change throttle value
void changeThrottle(int throttle) {
  int currentThrottle = readThrottle();
  
  int step = 1;
  if(throttle < currentThrottle) {
    step = -1;
  }
  
  // Slowly move to the new throttle value 
  while(currentThrottle != throttle) {
    writeTo4Escs(currentThrottle + step);
    
    currentThrottle = readThrottle();
    delay(throttleChangeDelay);
  }
}

//Read the throttle value
int readThrottle() {
  int throttle = esc1.read();
  
  Serial.print("Current throttle is: ");
  Serial.print(throttle);
  Serial.println();
  
  return throttle;
}

//Change velocity of the 4 escs at the same time
void writeTo4Escs(int throttle) {
  esc1.write(throttle);
  esc2.write(throttle);
  esc3.write(throttle);
  esc4.write(throttle);
}

//Init escs
void initEscs() {
  esc1.attach(escPin1, minPulseRate, maxPulseRate);
  esc2.attach(escPin2, minPulseRate, maxPulseRate);
  esc3.attach(escPin3, minPulseRate, maxPulseRate);
  esc4.attach(escPin4, minPulseRate, maxPulseRate);
  
  //Init motors with 0 value
  writeTo4Escs(0);
}

//Start the motors
void startUpMotors() {
  writeTo4Escs(50);
}
 
// Ensure the throttle value is between 0 - 180
int normalizeThrottle(int value) {
  if(value < 0) {
    return 0;
    
  } else if(value > 180) {
    return 180;
  }
  
  return value;
}

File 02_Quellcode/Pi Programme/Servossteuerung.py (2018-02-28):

import RPi.GPIO as GPIO
from time import sleep

GPIO.setmode(GPIO.BOARD)
GPIO.setup(11, GPIO.OUT)
pwm=GPIO.PWM(11, 50)
pwm.start(0)
GPIO.setmode(GPIO.BOARD)
GPIO.setup(13, GPIO.OUT)
pwm1=GPIO.PWM(13, 50)
pwm1.start(0)

def SetAngle(angle):
    duty = angle / 18 + 2
    GPIO.output(11, True)
    pwm.ChangeDutyCycle(duty)
    sleep(1)
    GPIO.output(11, False)
    pwm.ChangeDutyCycle(0)


def SetAngle1(angle1):
    duty = angle1 / 18 + 2
    GPIO.output(13, True)
    pwm1.ChangeDutyCycle(duty)
    sleep(1)
    GPIO.output(13, False)
    pwm1.ChangeDutyCycle(0)

#SetAngle links
SetAngle(40)
SetAngle(120)


#SetAngle rechts
SetAngle1(120)
SetAngle1(25)

#SetAngle(175)
#68 richtig 0 165np links
#40np // 205

pwm.stop()
pwm1.stop()
GPIO.cleanup()

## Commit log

2018-01-13 Erster Projektaufbau
    [DummyBaugruppe.iam, Dummybauteil.ipt]
2018-01-13 Nochmalige Ordnerumbenennung
    [DummyBaugruppe.iam, Dummybauteil.ipt]
2018-01-13 Platinenlayout Bereich erstellt
    [untitled.brd]
2018-01-15 Projektbeschreibung upload + Übungsunterlagen für evtl. SSH Zugang und Bilderkennung
2018-01-19 Anforderungsliste--> wird im unseren Fall gleich das LH, weil wir keine direkte Kundenabstimmung haben, sondern die Aufgabenstellung klar vorgegeben ist.
    [Anforderungsliste_LHGrundlage.xlsx]
2018-01-19 Projektmanagement - Assignment 5 Template hochgeladen und vorbefüllt
    [Anforderungsliste_LHGrundlage.xlsx]
2018-01-20 Add files via upload
    Grundkonzept Chassis
    [Chassis-1.ipt]
2018-01-20 Add files via upload
    Deckel Chassis
    [Chassis-2.ipt]
2018-01-20 Raspberry pi und Motoren inMohne Baugruppe eingefügt
    [01000A-010-001-PN.ipt, 01000A-040-001-SC.ipt, 01000A-040-001-UE.ipt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]
2018-01-20 Add files via upload
    Version: 200118_1525
    [Chassis-1.ipt]
2018-01-20 Add files via upload
    Chassis-1
2018-01-20 Add files via upload
    Bauteile Chassis
    [Achsenhalterung.ipt, Chassis-2.ipt, Platzhalter Zylinder Groß.ipt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]
2018-01-20 Technische Zeichnung Motoren
2018-01-20 ich habe gebaut: - Löcher für die Motoren im Chassis - Gehäuse für Motoren
    [Chassis-1.0004.ipt, Chassis-1.ipt]
2018-01-20 schau hi
    [Gehäuse Motor.ipt, chassis mit motorlöcher.ipt]
2018-01-20 Mohne geupdated
    [Base.SLDPRT, Base.ipt, MPU 6050 IMU.SLDASM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]
2018-01-20 chassis eingefügt
    [01000A-050-Motor Bearing.0001.iam, 01000A-050-Motor Bearing.iam, Chassis-2.0002.ipt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]
2018-01-21 Add files via upload
    Schau mal ob des so passt!
2018-01-21 PM für Freitag: Dateiname ist - Assignment 5: christoph und anna
    [Phases PM.xlsx]
2018-01-21 Alles zusammengefügt und eigene Folien eingearbeitet. HANDOUT FEHLT NOCH. :-)
2018-01-22 Meinen Teil ins Handout eingepflegt und minimal angepasst, Rechtschreibfehler in ppt korrigiert
2018-01-22 Christophs Teil eingefügt und Formatierung geradegezogen
2018-01-24 Kosten zusammengetragen
    [Kostenaufzählung.xlsx]
2018-01-26 Fertige Teile Mohne + Gesamte Mohne
    [Chassis-1.ipt, Chassis-2.ipt, Erhöhung.ipt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]
2018-01-26 Servomodel eingefügt und Stirnrad konstruiert.
    [Kegelrad.0001.iam, Servo HXT900 Micro.ipt, StirnradUNDServo.iam]
2018-01-27 Servohalterung mit Zahnräder
    [L-Halterung Servo.0004.ipt, L-Halterung Servo.ipt, L-Halterung Servo_MIR.0001.ipt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]
2018-01-27 Testeil für Plotter
    [Testteilx.dxf, chassis mit motorlöcher.dwg]
2018-01-27 3D Druck teile exportiert
    [L-Halterung Servo.stl, Mohne komplett.0005.iam, Mohne komplett.0006.iam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]
2018-01-28 svg chassis
    [chassis1.dwg, chassis1.dxf]
2018-01-29 Referenzen wieder hergestellt
    [Peça7^Servo HXT900 Micro.ipt, Servo HXT900 Micro - Carcaça Inferior.ipt, Servo HXT900 Micro - Carcaça Intermediária.ipt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]
2018-01-29 Konstruktion abgeschlossen bis auf Kamerahalterung
    [28-2-2013-001 - ESC Flyduino SimonK 20A body.SLDPRT, 28-2-2013-002 - ESC 3-pin connector.SLDPRT, 28-2-2013-100 - ESC Flyduino SimonK 20A.SLDASM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]
2018-01-29 Bild vom CAD Modell
2018-01-29 Update README.md
    CAD Modell unserer Mohne :-)
2018-01-30 Kamerahalterung von Anna in Komplettmodell eingepflegt, ebenso Radaufhängung von Christoph. Neues Bild erstellt. Exprte für 3D Druck und Lasercut erstellt.
    [Abstandhalter_MPU.stl, Achse.ipt, Chassis_zweiteEbene.0001.dwg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]
2018-02-03 Add files via upload
    Servosterung für beide Mountingbladeservos
2018-02-09 ESC Steuerung mit Hilfe der Servo Library
2018-02-10 Create servo + ultra
2018-02-10 Update servo + ultra
2018-02-25 Stückliste Mohne
    [Stückliste.xlsx]
2018-02-28 Ordner Umbenannt
    [untitled.brd]
2018-02-28 Upload der Programme auf dem Pi: Zahleni2c ist die Schnittstelle vom pi zum arduino, Servosteuerung steuert die Servos direkt vom Pi und color2 ist die Farberkennung mittels Kamera. Der Rest sind Tes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
2018-03-10 Bilderordner und Arbeit am Projektbericht
2018-03-10 Kompletten Projektbericht überarbeitet, Diagramme und Grafiken angepasst.
    [Anforderungsliste_LHGrundlage.xlsx]
2018-03-11 Fertigstellung bericht und UMLs
2018-03-11 PDF und zip Umwandlung - Chris
